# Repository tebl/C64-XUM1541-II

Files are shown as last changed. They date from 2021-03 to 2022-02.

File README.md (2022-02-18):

# C64 XUM1541-II
About a year ago I had a look at my collection of Commodore 64 floppies and decided that it was time, enough time had passed that even I needed to look into backing them up - hoping simply doesn't cut it in the end. I had a look at the available options, then instead of just choosing to buy something like the ZoomFloppy I wanted to build it myself. With the resources available to me [online](https://myoldcomputer.nl/commodore-64/xum1541-promicro/), all of the heavy lifting was already done. The work of transferring the designs to PCB using KiCAD resulted in the previous version, creatively called [C64 XUM1541](https://github.com/tebl/C64-XUM1541). Now that a year has gone by, mostly isolated like most of the world I wanted to make a new revision with few tweaks and so I made the  *C64 XUM1541-II*.

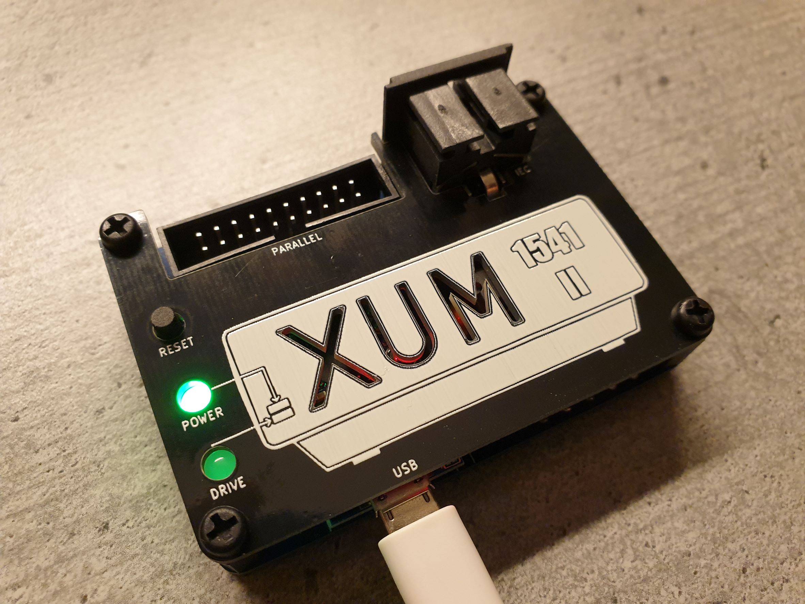
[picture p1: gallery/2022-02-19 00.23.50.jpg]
C64 XUM1541-II with faceplate

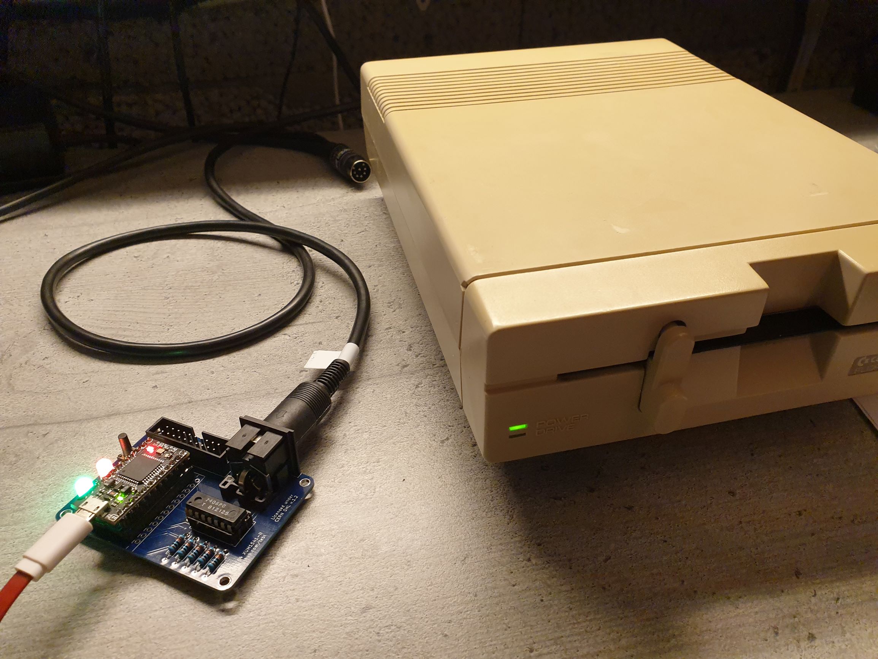
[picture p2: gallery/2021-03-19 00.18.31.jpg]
C64 XUM1541-II


What had somewhat annoyed me that the [C64 XUM1541](https://github.com/tebl/C64-XUM1541) was its apparant limition when it came to running anything past version 0.7 of the [OpenCBM](https://github.com/OpenCBM/OpenCBM/tree/master/xum1541) firmware, so I finally got around to actually reading the documentation that came with it. I don't know the exact point in time the designs parted ways, but thinking practically - I instead just focused on making a version of it that would work. Mostly by adding the components required for the 7406-version of the reference design included with *OpenCBM*.

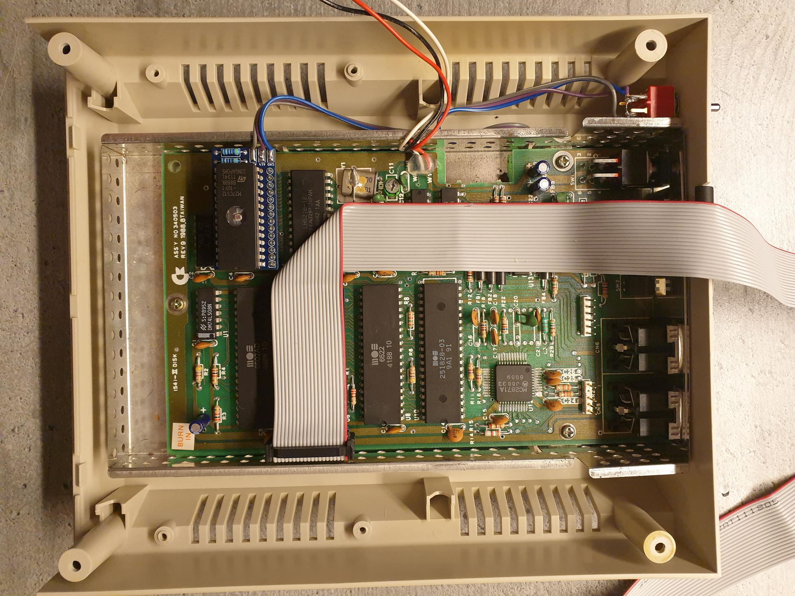
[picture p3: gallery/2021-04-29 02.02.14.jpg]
Internal upgrades


Not quite substantial enough to warrant documenting them as separate projects, I've also taken a look at implementing some of the simpler upgrades for the Commodore 1541-II as they are the type of drives I have available. Read through the included documentation before attempting to perform any of the upgrades as well as ensuring that they actually fit into the drive you have.

# 1> Modules
The following modules are available as part of this project. The additional modules are strictly not necessary as you can simply use the *C64 XUM1541-II* by itself with a drive, the parallel interface will cut the time needed to backup a single disk in half. The remaining modules mainly just affect your experience when using the drive with your physical Commodore 64, but note that most of them have been designed for use with a Commodore 1541-II disk drive.  The SpeedDOS user port adapter has been included for completeness, but before getting excited about the possiblities you should be aware that the speed gains will probably be less than what you'd obtain by simply installing [JiffyDOS](http://store.go4retro.com/categories/Commodore/Firmware/JiffyDOS/) in your [disk drive](http://store.go4retro.com/jiffydos-1541-dos-rom-overlay-image/) as well as  the [computer](http://store.go4retro.com/jiffydos-64-kernal-rom-overlay-image/) itself.

The following table lists all of the modules, click the name to get a more detailed description as well as other information for that specific module. The second and third column has been added to show which module can be used with each other, the 'XUM1541' giving a recommendation when performing backups on a modern computer. The  third column provides a recommendation when you want to use the modified drive with your physical Commodore 64.

| Module | C64 XUM1541-II | Physical C64 | Order  | Description |
| --- | --- | --- | --- | --- |
| [C64 XUM1541-II](https://github.com/tebl/C64-XUM1541-II/tree/main/C64%20XUM1541-II) | required | N/A | [PCBWay](https://www.pcbway.com/project/shareproject/C64_XUM1541_II.html) | C64 XUM1541-II module for backing disks up to modern computer.
| [C64 XUM1541-II Faceplate](https://github.com/tebl/C64-XUM1541-II/tree/main/faceplates) | optional | N/A | [PCBWay FA1](https://www.pcbway.com/project/shareproject/C64_XUM1541_II__Faceplate_FA1_.html) | Optional faceplates suitable for installing on top of [C64 XUM1541-II](https://github.com/tebl/C64-XUM1541-II/tree/main/C64%20XUM1541-II), hiding away most of the electronics in a way that would mimic a case with a minimal amount of work.
| C64 1541-II VIA Adapter | recommended | optional | PCBWay | Adds a parallel interface to your Commodore 1541-II disk drive, can be used with both [C64 XUM1541-II](https://github.com/tebl/C64-XUM1541-II/tree/main/C64%20XUM1541-II) as well as physical computer with a suitable ROM upgrade.
| [C64 1541-II ROM Adapter](https://github.com/tebl/C64-XUM1541-II/tree/main/C64%201541-II%20ROM%20Adapter) | optional | recommended  | PCBWay | Adds a switch to select between ROM images suitable for Commodore 1541-II disk drive with only a single 16KB ROM chip.
| C64 SpeedDOS Adapter | N/A | optional | PCBWay | User port adapter for connecting a 1541-II disk drive with a parallel cable up to your Commodore 64, requires matching firmware on the drive as well as the computer.
| [C64 Kernal Switcher](https://github.com/tebl/C64-Kernal-Switcher) | N/A | recommended  | [PCBWay](https://www.pcbway.com/project/shareproject/Commodore_64_Quad_Kernal_Switcher.html?inviteid=88707) | Using a custom kernal with optimizations for either serial or parallel interfaces is recommended. This board was designed for use with C64 "Longboards".

# 2> Documentation
Building an XUM1541 from scratch and getting the software ready to transfer your own physical disks, is a rather involving process. It is an afternoons worth of a project, but by following the documentation it shouldn't be a difficult task for anyone equipped with a brain for slight engineering. As the project really is just a collection of various modules that you may or may not need, I've separated the information so that the relevant documentation is included as a separate README for each of the [modules](#1-modules) - click the module name for BOM, build instructions and so forth.

When you're ready to start installing software, by first installing the firmware onto the *Arduino Pro Micro* and then installing OpenCBM, there's a separate document covering these details:
- [Firmware installation](https://github.com/tebl/C64-XUM1541-II/blob/main/documentation/firmware.md)

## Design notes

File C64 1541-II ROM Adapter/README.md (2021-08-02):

# C64 1541-II ROM Adapter
The ROM found within the Commodore 1541-II disk drives requires 16KB chips which are somewhat of a pain to source in an age where most kids carry a supercomputer in their pocket, but for some reason the 32KB 27C256 and the 64KB 27C512 are practically leaking out of post box. You could just hardwire the extra pins to use only part of the capacity, or you could add a bunch of switches and a bunch of wires to have a selection firmwares ready at the flick of a switch without needing this adapter. I just love adding little boards everywhere because I'd know that something was hacked in there, so that's the reason this board exists. Note that earlier 1541 drives used two ROM chips, so for those you'd need a different solution that is presented here.

Worthy of noticing early on, is that the 1541-II doesn't really have very much available space to work with, so there will be some compromises that needs to be made in order to fit everything in the space available. For that reason I recommend following the supplied build instructions, only deviating once you've understood the reason for building it in this way.

- [1> Building it](#1-building-it)
  - [1.1> Soldering it together](#11-soldering-it-together)
  - [1.2> Preparing the EPROM](#12-preparing-the-eprom)
  - [1.3> Testing it out](#13-testing-it-out)
- [2> Schematic](#2-schematic)
- [3> BOM](#3-bom)

# 1> Building it
Building the unit assumes you have at least minor experience soldering things together, recommended is at least a soldering station with adjustable temperature to get started. Commonly you'll want to start out with some 60/40 solder tin, but this'll naturally depend on availability in your area.

With the requirements when it comes to equipment sorted, now it's time to do even more shopping - head on over to the [BOM](#3-bom)-section for a specific list over components needed. Note that with sites such as ebay, AliExpress and similar sites that sell cheap chinese components, you'll need to treat these more as a suggested search term and look for something that for the most part matches the gallery pictures. I tend to use only the cheapest components available, so it should be somewhere in the top of your results.

Remember that part where I told you there'd be compromises? The first one is that the assembled adapter would be too tall to fit under the drive mechanism, meaning that we'd only be able to fit a single DIP socket. Your options are to either to remove the one already found on the 1541-II mainboard, or you need to solder the EPROM chip directly to the adapter board. I personally prefer the latter, I can always build another adapter board if it comes down to it - so this is also the solution that will be described when going forward.

## 1.1> Soldering it together
I suggest that you start out by studying the PCB so that you have a general overview over the components that are needed, In particular, pay attention to the markings on the board for the components that need to be installed in a specific orientation such as the EPROM. The pins marked with the circles around them will be used for the pins that will pass through the board and into the 1541-II mainboard socket below, note that one of these rows will be underneath the EPROM.

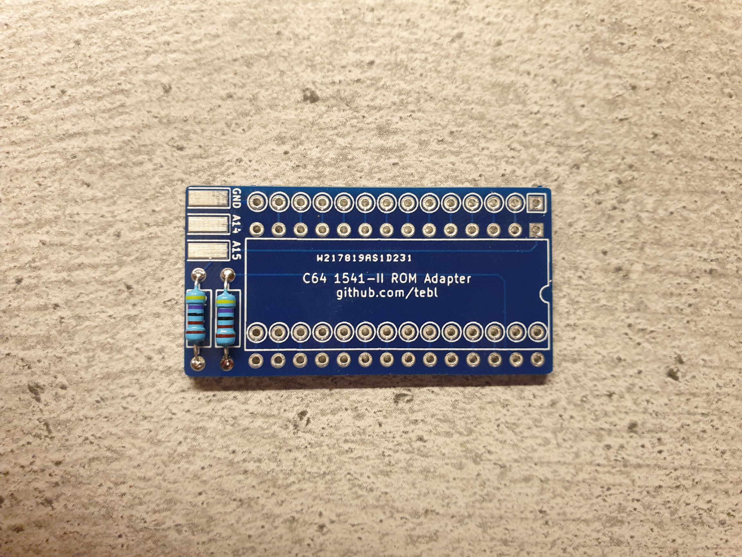
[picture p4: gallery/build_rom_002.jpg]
Build C64 XUM1541-II 002


Here we've gone ahead and installed the two resistors needed, there isn't much else to say about the matter. If the silkscreen fits, then you must commit and all that - just to say more than what was strictly needed (there is no polarity).

Here we've gone one step further by getting started on the pins that will go into the socket found on the 1541-II mainboard, because of the height limitations we won't be able to simply use pin headers as expected. We'll instead need to use the *"neat"* method instead, simply put by using the long pin versions of female pin headers. Using a temporary socket as a template, lightly solder the top of the pins to the adapter board using as little solder as possible. When done, observe the result from the underside to ensure that the solder has flowed into and filled the hole completely to ensure that it won't simply fall apart later. Cut off the top of the pins as close as you can to the adapter board, in particular those that will be overlapped by the EPROM. For reference, the holes that we're soldering components to at this point is marked with rings around the holes.

When happy with the results, we're ready to solder in an already prepared EPROM (27c256/27c512) or EEPROM (w27c512). Check out section [1.2> Preparing the EPROM](#12-preparing-the-eprom) if you need a bit of guidance when putting data onto the chip before soldering it to the board. You can have a total of four different ROM images when using the 27c512 or w27c512 chips, but I tend to only install a single DPDT (ON-OFF-ON) switch - giving me three different usable images instead of four without needing to add a second switch. Solder the chip into place once you've got the correct data on it, trim the pins to ensure that they don't accidentally make contact with something it's not supposed to.

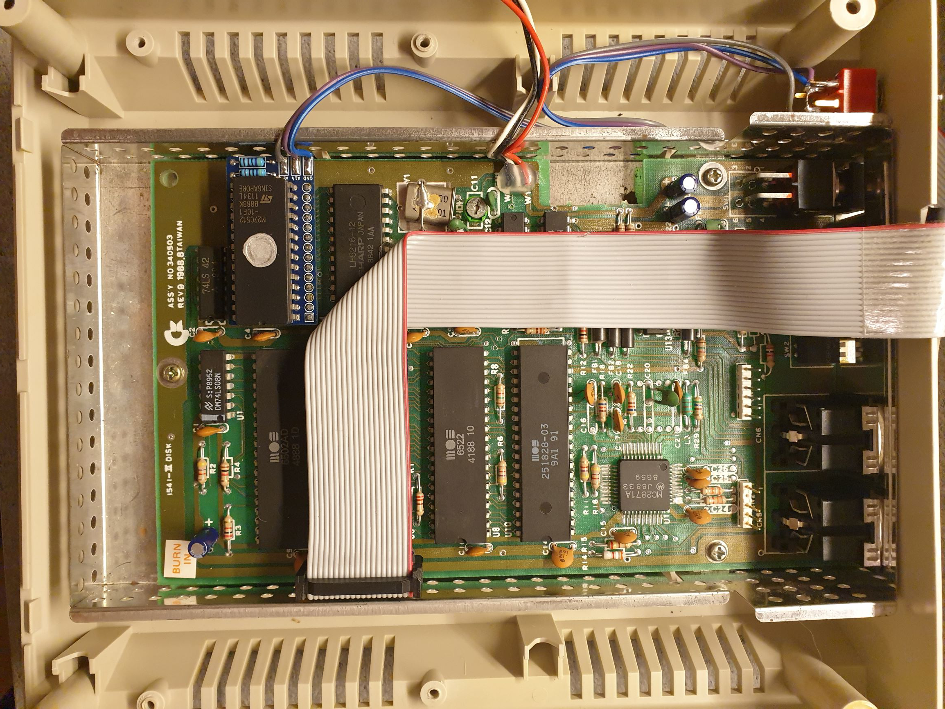
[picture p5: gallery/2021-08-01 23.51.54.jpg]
Switch installation


The DPDT has 6 pins, the easiest way of wiring it up is to connect the two center pins to the point marked GND. The two address lines is connected on either of the sides, but not on the same row. Doing it this way means that the first 16K image will never be accessed, putting the switch in the center position will be the last 16K image (ideally the original firmware). Even with the RF-shield in place, there's plenty of room on the sides - just remember to measure once and drill as many times as it takes.

## 1.2> Preparing the EPROM
The Commodore 1541-II drive has a single ROM socket on the mainboard and as already mentioned it is 16K in size, so with a 27c512 in place on the adapter we'll have the capability of selecting between four different 16K slots. When only installing a single DPDT-switch as described in the previous section, we'll only have access to the last three slots though we'll just be putting the default ROM there as well (in case we change our mind about it at a later point).

To be honest there isn't all that much that makes sense to install in the slots, the most common is using [JiffyDOS](http://store.go4retro.com/jiffydos-1541-dos-rom-overlay-image/) as well as the original firmware referred to as [1541-II.251968-03](http://www.zimmers.net/anonftp/pub/cbm/firmware/drives/new/1541/). Given that I wanted to play around with [SpeedDOS](http://www.zimmers.net/anonftp/pub/cbm/firmware/drives/new/1541/hacks/), I'm using that as the third alternative. Merging the four files together into a 64K file ready for flashing onto the aforementioned 27c512 chip can be done like the following:

```
copy /b 1541-II.251968-03.bin + JiffyDOS_1541-II.bin + 1541-II-relocated.bin + 1541-II.251968-03.bin 1541-II-firware.bin
```

Flash the file onto your actual chip using an EPROM burner such as the MiniPro TL866, there should be plenty of information on doing this out there on the wet and wild Internet.

## 1.3> Testing it out
Initial testing of the replaced ROM using the adapter is easily done by simply turning on the drive and observe that is turns on, spins the drive and then finally stops again (this is a good sign that the drive is working as expected). The various ROM replacements will normally write a different string to the error channel, when used with a device such as the XUM1541 or XUM1541-II this is the drive identification when using OpenCBM (*cbmctrl.exe detect*).

With the drive turned off, flick the switch or switches that you may or may not have installed. Probably wouldn't hurt anything if you forget to switch it off, but there's not much of a chance that it'll do much else than crash once the ROM suddenly gets replaced. Note down the values you get and the position of the switches, mark accordingly so that you don't need to guess at a later point.

# 2> Schematic
The supplied KiCad files should be sufficient as both a schematic and as a  starting point for ordering PCBs (basically you could just zip the contents of the export folder and upload that on a fabrication site), the schematic is also available in [PDF-format](https://github.com/tebl/C64-XUM1541-II/tree/main/documentation/schematic) and this is what you'll need to print and work your way through this things don't work as expected after assembly.

# 3> BOM
Most parts should be easy to get a hold of from your favourite local electronic component shop, but given that I don't have access to such shops where I live so everything was based on whatever I could get cheapest from eBay/AliExpress (free shipping, but plan on waiting 3-4 weeks for delivery). 

| Reference | Item | Count | Order  |
| --- | --- | ----- | --- |
| Adapter PCB | Fabricate using Gerber files | 1 | [PCBWay]()
| R1,R2 | 4k7 (4700) ohm resistor | 2
| A1 * | 2.54mm long female pin headers of suitable length | 2
| U1 | 27C256, generic 27C512 EPROM or a W27C512 EEPROM | 1
| SW | DPDT On-Off-On switch and hookup wire

*) Given that we are only using parts of the female pin headers with long pins, we don't really need a specific amount of pins though you'll have an easier time if you kind find ones with at least 14 pins (the remainders would either be cut off or used for a different project). This is described in more detail in the build section.

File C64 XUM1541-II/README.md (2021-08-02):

# C64 XUM1541-II
If you came to this github-repository looking for the implementation of an XUM1541, then you've come to the correct place and this folder contains all of the files needed to build one for yourself. The necessary details first of course, I didn't design the original XUM1541 - the earlier heavy lifting was already done and detailed in an  article [online](https://myoldcomputer.nl/commodore-64/xum1541-promicro/). My contribution was reading it, then adapting it for easier use by designing a PCB as part of a personal project available at [C64 XUM1541](https://github.com/tebl/C64-XUM1541).

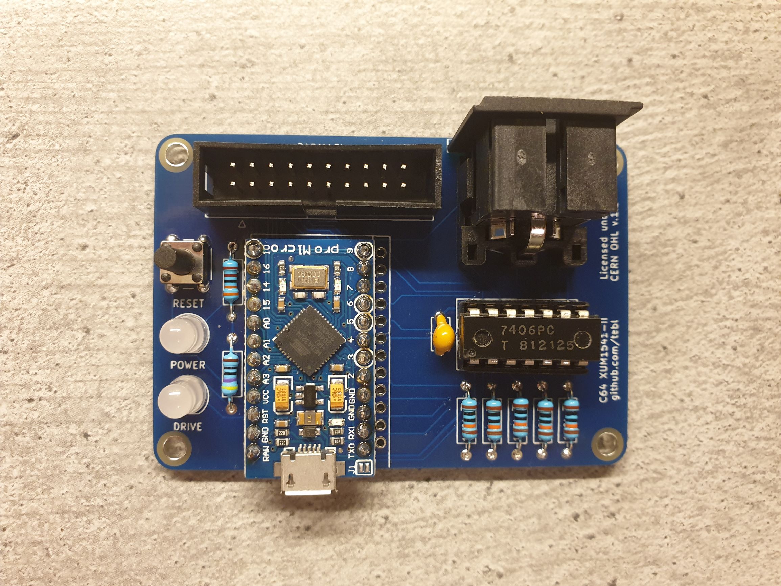
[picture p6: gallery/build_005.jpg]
C64 XUM1541-II


This however is an updated version from that design, mainly by integrating the 7406 inverter as described in the [OpenCBM](https://github.com/zyonee/opencbm/tree/master/xum1541) documentation. In theory this should allow the device some more durability when used together with multiple devices connected to the IEC-bus, but while I haven't had any issue with the original device - the main objective was to modify it for use with the later versions of the OpenCBM firmware (0.8). A secondary objective was to make it a more visually pleasing device from the original, which is pretty hard when dealing with a bare PCB - so I designed a separate faceplate to be installed on the top though this is a completely optional addition.

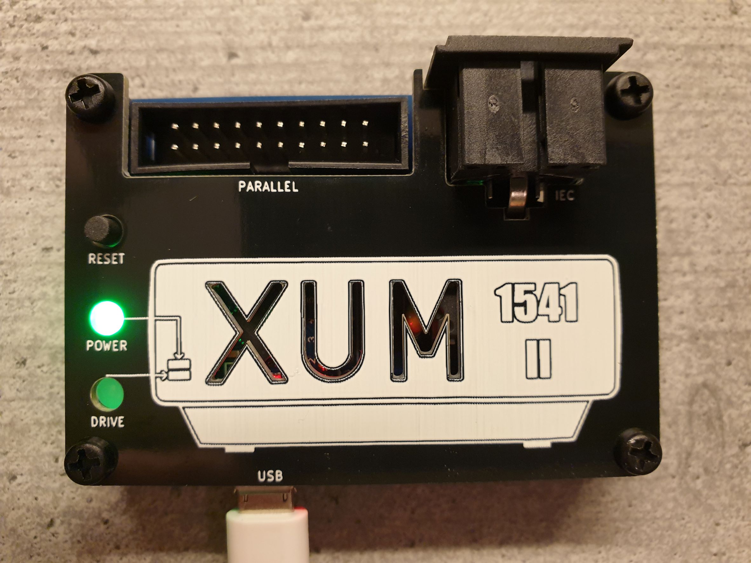
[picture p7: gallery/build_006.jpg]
C64 XUM1541-II with faceplate


- [1> Building the C64 XUM1541-II](#1-building-the-c64-xum1541-ii)
  - [1.1> Soldering it together](#11-soldering-it-together)
  - [1.2> Assembling the unit](#12-assembling-the-unit)
  - [1.3> Testing it out](#13-testing-it-out)
- [2> Schematic](#2-schematic)
- [3> BOM](#3-bom)

# 1> Building the C64 XUM1541-II
Building the unit assumes you have at least minor experience soldering things together, recommended is at least a soldering station with adjustable temperature to get started. Commonly you'll want to start out with some 60/40 solder tin, but this'll naturally depend on availability in your area.

With the requirements when it comes to equipment sorted, now it's time to do even more shopping - head on over to the [BOM](#3-bom)-section for a somewhat specific list over components needed. Note that with sites such as ebay, AliExpress and similar sites that sell cheap chinese components, you'll need to treat these more as a suggested search term and look for something that for the most part matches the gallery pictures. I tend to use only the cheapest components available, so it should be somewhere in the top of your results.

## 1.1> Soldering it together
The construction of this unit should be straight-forward, specifically as there are only a handful of components to deal with. None of the components overlap in any way, so while there are certainly an easier route - that one would normally go from first installing the smallest components and working your way up from there. 

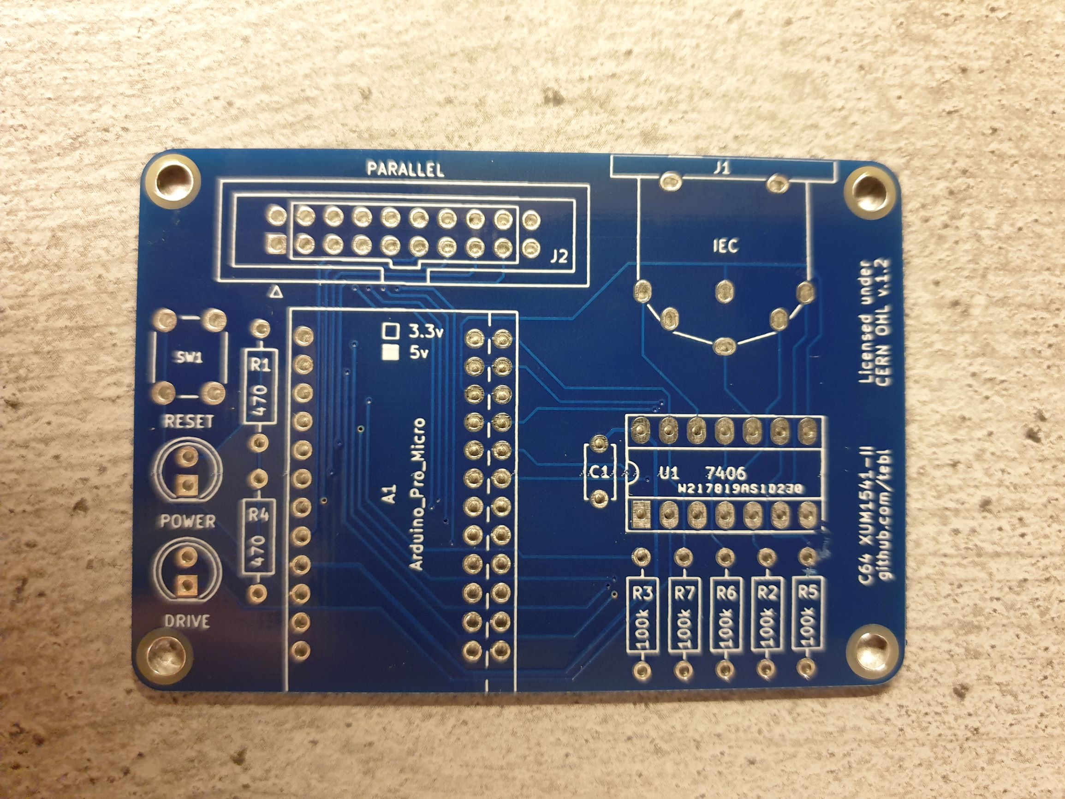
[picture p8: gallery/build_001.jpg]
Build C64 XUM1541-II 001


I suggest that you start out by studying the PCB so that you have a general overview over the components that are needed, possibly also making a mental note over the components specificly listed in the BOM as optional (component count in parenthesis). In particular, pay attention to the markings on the board for the components that need to be installed in a specific orientation (LEDs and the single IC socket).

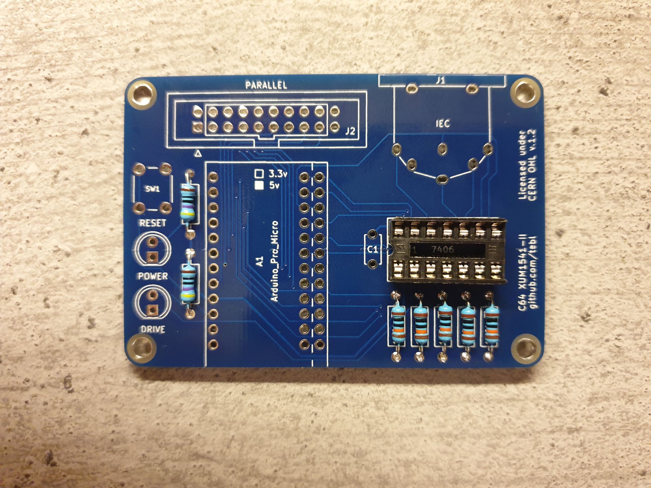
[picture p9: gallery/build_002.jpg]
Build C64 XUM1541-II 002


Here we've gone ahead and installed all of the resistors, if you've bought the components as part of a kit you should note that there are two different values that you can easily pick out based on their colour bands and the number included. The IC socket have an indent on one side, this should be matched to the silkscreen on the board.

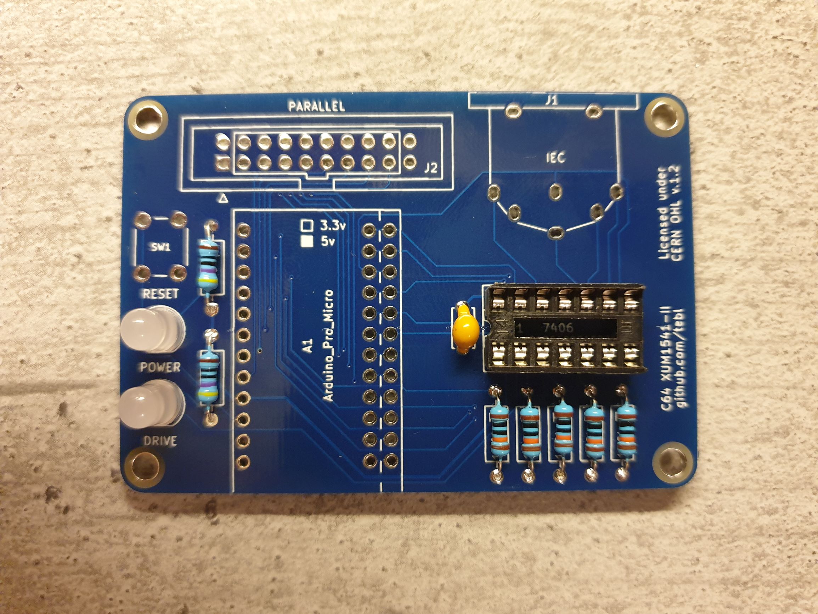
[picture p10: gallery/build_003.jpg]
Build C64 XUM1541-II


The single capacitor doesn't have a polarity so just stick it in place. The LEDs won't function when installed in the wrong orientation, ideally this should be as easy as matching the flat side to the one on the board. However there are quite a few cheaper LEDs where this isn't as easy to determine, so instead I'll just recommend that you put the shortest pin into the hole on the *flat* side. Given that you'll no doubt want a faceplate, you need to get this on the board straight - what I recommend is that you solder one of the pins, then reheat and push the component flush with the board before soldering the remaining pin.

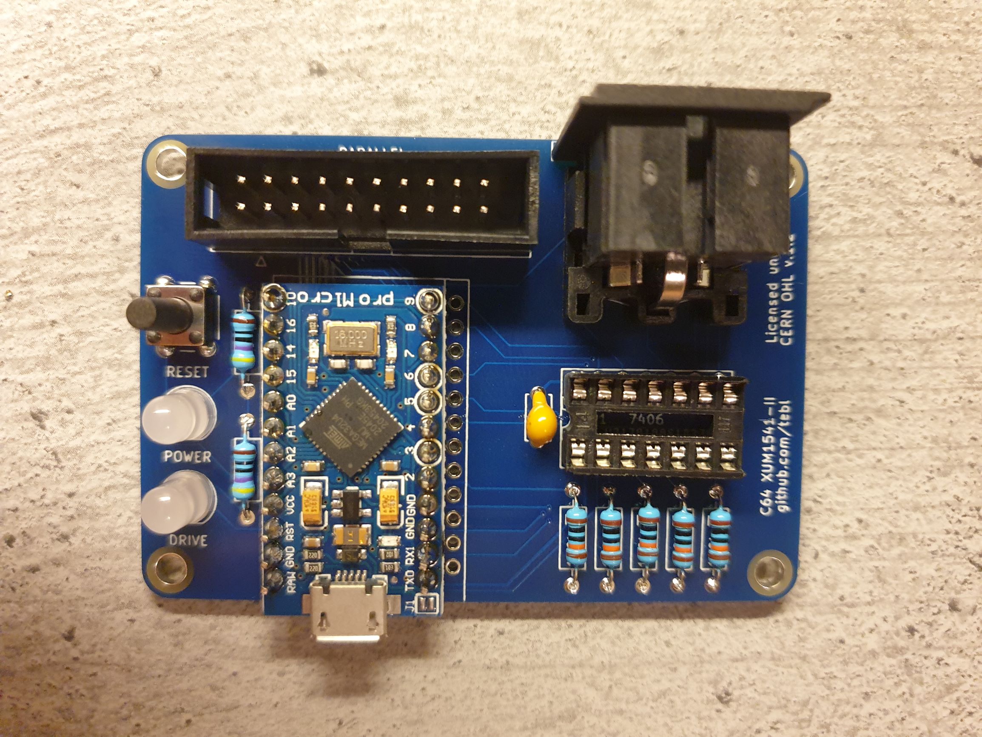
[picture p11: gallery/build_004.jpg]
Build C64 XUM1541-II

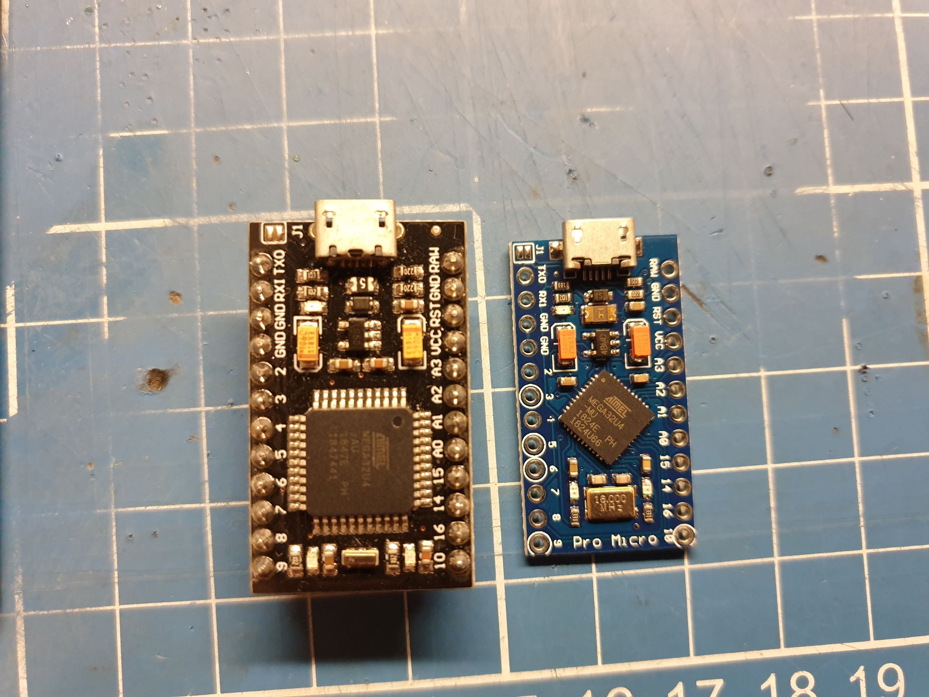
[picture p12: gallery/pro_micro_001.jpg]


Here we've jumped a bit ahead and finally you've found the answer to one of your original questions; why does the outline for the Arduino Pro Micro have three sets of pins on it? As you can see from the other picture added, there are a few different layouts for the Arduino Pro Micro boards - one is wider than the other! Pick the one that matches your boards before soldering pin headers onto either of the modules.

The last component that we really need to discuss is the momentary switch, mainly that it needs to be tall enough to poke through the faceplate on top. I've not found out how ebay listings measure the height of their switches, mainly because I just picked up a kit with different size switches and picked what fit. What I can tell you is that measuring just the black protruding plastic part, it needs to be around 8mm - measured from the PCB it sits around 11.5mnm above it.

Time to shut off the soldering iron. Feel the strongth welling, return to the next chapter for the exciting conclusion to this documentation. Spoiler warning: there will be a section after that one.

## 1.2> Assembling the unit
At this point we've added just about everything but the 7406, mainly just because I like dragging things out. Before doing so, I recommend spending some time to get the firmware installed onto the Arduino Pro Micro. It shouldn't matter, but it given the number of fake 7406 chips floating around it's better doing it this way. Given that installing the firmware and the accompanying OpenCBM software can be a bit more difficult than it should be, I've put together a separate [document](https://github.com/tebl/C64-XUM1541-II/blob/main/documentation/firmware.md) that should go into just about every bit of details needed to get all that set up. Return here when you're ready to move onto testing things out.

Build C64 XUM1541-II

Here we've inserted the aforementioned 7406, and the device should now be ready for actual testing. Skip to the next chapter if you don't want a faceplate, because - why wouldn't you want a faceplate? They're cool.

Build C64 XUM1541-II

The faceplate is just a simple PCB, the suggested way of attaching it is by using components found in cheap *M3 nylon hex* kits. It will look at its best when using an 8mm nylon hex standoff (F-F), then adding screws from both sides. If, on the other hand, you want to stay within the kit - then I suggest using the 8mm M-F standoffs, add M3 nuts on the bottom and snip off the remaining part of the nylon screw that'll poke through. Add screws on top.

## 1.3> Testing it out
When ready to test things out, we need to do some safety notifications - mainly, you can't buy any new and unused Commodore 1541 disk drives so treat them with care. They aren't plug and play like we're used to today, if you start plugging and unplugging cables while things are powered on you should probably say a prayer. Neither probably won't actually cause your vintage computer hardware to explode, but it'll happily kill your hardware in less spectacular ways. Got that? Good.

Ensure that the 1541 disk drive as well as the C64 XUM1541-II is not powered on, now connect the  IEC cable between them. Power on the disk drive, then plug the device into your modern computer. Go through the final section of my [firmware]([document](https://github.com/tebl/C64-XUM1541-II/blob/main/documentation/firmware.md)) document for some initial hints on copying your first disk, check out the software directory for a few of the batch files I personally use with the device if you just want some basic functionality without looking into all of the options (see OpenCBM documentation for that).

# 2> Schematic
The supplied KiCad files should be sufficient as both a schematic and as a  starting point for ordering PCBs (basically you could just zip the contents of the export folder and upload that on a fabrication site), the schematic is also available in [PDF-format](https://github.com/tebl/C64-XUM1541-II/tree/main/documentation/schematic) and this is what you'll need to print and work your way through this things don't work as expected after assembly.

# 3> BOM
Most parts should be easy to get a hold of from your favourite local electronic component shop, but given that I don't have access to such shops where I live so everything was based on whatever I could get cheapest from eBay/AliExpress (free shipping, but plan on waiting 3-4 weeks for delivery). 

| Reference | Item | Count | Order  |
| --- | --- | ----- | --- |
| Cartridge PCB | Fabricate using Gerber files | 1 | [PCBWay](https://www.pcbway.com/project/shareproject/C64_XUM1541_II.html)
| Faceplate PCB | Fabricate using Gerber files | (1)| [PCBWay FA1](https://www.pcbway.com/project/shareproject/C64_XUM1541_II__Faceplate_FA1_.html)
| A1 * | Arduino Pro Micro | 1 |
| C1 | 100nF ceramic capacitor (5mm pin spacing) | 1 |
| D1,D2 | 5mm LED | (2)|
| J1 | Female S-terminal 6pin DIN PCB | 1 |
| J2 | 2x10 male IDC socket | (1) |
| R1,R4 ** | 470 ohm resistor | (2)| 
| R2,R3,R5,R6,R7 | 100k ohm resistor | 5 | 
| SW1 | 6x6x11mm right-angle momentary button | 1 |
| U1					| 7406 (DIP-14) | 1 |
| Mounting *** | Nylon M3 hex standoffs 8mm | (4)|
| Mounting *** | Nylon M3x6mm nylon screws | (4)|
| Mounting *** | M3 nylon nut | (4)|  

*) I've purchased a couple of different Arduino Pro Micro boards that had a different physical size, so take care to match up the pins to the PCB so that you solder it up to match the board you own. 

**) The value to be installed here needs to match the LEDs installed, value should be acceptable for most cheaper LEDs. If the using LEDs in any way listed as bright or are in any way clear, you'll need to calculate a suitable value in order to not blind yourself when looking at them.

***) The easiest way of ordering these is to just one of the M3 nylon standoff kits on ebay, AliExpress or any similar sites. That way you'll get more than what you need in various sizes for future projects as well.

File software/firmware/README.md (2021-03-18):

The firmware found in this directory was distributed as part of the repository at https://github.com/zyonee/opencbm/tree/master/xum1541. It is included here as a last known working firmware revision, later versions may have updates that have not been tested with this device.

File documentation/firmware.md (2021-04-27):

# 1> Firmware installation
The firmware that goes onto the Arduino Pro Micro is often referred to as an  Arduino Sketch, something that isn't actually fitting in this case as the design uses the hardware without the software parts of the Arduino project - we'll be flashing the Atmel Atmega32 MCU directly using more generic tools instead. The next step is installing a suitable USB-driver followed by the OpenCBM software package.

This document will for the most part focus on MS Windows as that is what I have, for all other systems you'll need to fill in quite a few of the gaps yourself. While you may not need to perform all of these steps exactly as described within this document, there are enough of little pitfalls that you can quicly fall into. For that reason I recommend that you read through the entire document before attempting to install any of the components, then do **exactly** as described. 

- [1.1> Flashing AVR](#11-flashing-avr)
- [1.2> Install USB-driver](#12-install-usb-driver)
- [1.3> Install OpenCBM](#13-install-opencbm)
- [1.4> Try copying a disk](#14-try-copying-a-disk)

## 1.1> Flashing AVR
While we could download the source code for the firmware and compile it ourself from the authors [github](https://github.com/zyonee/opencbm)-repository, we're instead going to use a precompiled version of the firmware instead - it'll be distributed as an Intel HEX-file. This is the same file type as used by EPROM burners such as the MiniPro TL866 referred to elsewhere in this project, but that would require knowing intuitively how to set the fuses for the MCU - I have no idea about such things, so I recommend using a program specificly made for dealing with MCUs.

One such program, it is also the one I'll be referring to for the remainder of this document, is usually referred to as just - *avrdude*. A distribution of this software that has been prepared for installation on a modern copy of MS Windows is [WinAVR](https://sourceforge.net/projects/winavr/). With other operating systems you'll probably find a similar package as it's practically available everywhere, ignore the obvious Windows-stuff when going forward.

At this point, you should already have installed a version of *avrdude*. The next step is just simply downloading the HEX-file as mentioned earlier, you can grab current version I've verified working from my [repository](https://github.com/tebl/C64-XUM1541-II/tree/main/software/firmware) or a bleeding edge copy from the original authors [repository](https://github.com/zyonee/opencbm/tree/master/xum1541). Given that the *C64 XUM1541-II* hardware integrates a 7406 inverter, it should be named  "xum1541-PROMICRO_7406-v08.hex" (depending on version).

**NB!** When downloading the file, make sure that you save this file from the raw-format - simply right-clicking a file from within the github-page will save it along with a bunch of html inside it. Click the file, then the *RAW* button - then finally save the file with the proper content. Alternatively you can view the repository in the web-browser, click the green *Code* button and then select *Download ZIP* to get a copy of everything.

Before we can flash the Arduino Pro Micro, we'll need to know which COM-port Windows have assigned to your it. Connect it to your computer using a suitable USB-cable, try a different one if nothing at all happens on your computer at this point - usually it'll make a *ding* sound or something to that effect. Check out *device manager* and take a look at the Ports-section, you should have one here - this is **NOT** the one you want! The one you actually want to use will only be shown for 8 seconds, so keep this window open and reset the Arduino Pro Micro by pressing the reset button **twice**.

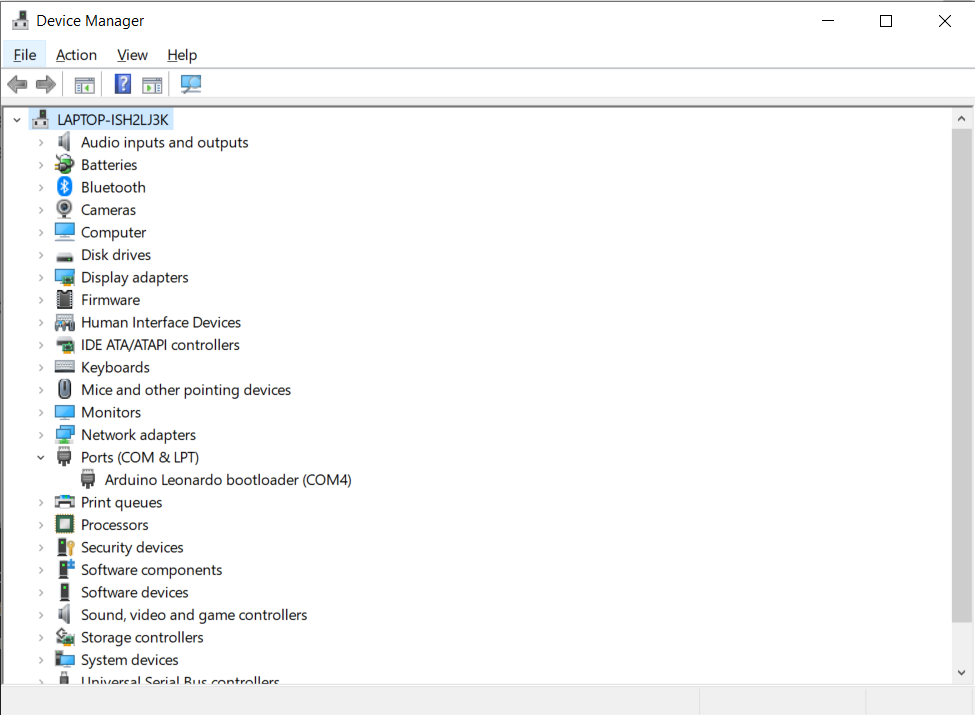
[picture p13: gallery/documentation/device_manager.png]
device_manager


On my computer the port showed up as com4, you need to pay attention and make a note of what this number is on your computer. After the already mentioned 8-second timeout it'll change again, but never mind that - as it is this first one we need to use with *avrdude*. Type in the command as below, substituting your actual com-port, but do **NOT** press ENTER at this point. Reset the Arduino Pro Micro again by pushing *reset* **twice** and then quickly press ENTER to run the command (you'll have 8 seconds). 

```
avrdude -p m32u4 -c avr109 -P com4 -U flash:w:xum1541-PROMICRO_7406-v08.hex
```

If all things go as expected you should get something like the following, just ignore the specifics and ensure that it at the moment verifies that the firmware was written correctly. If it times out or bombs out with an error message, you were probably too late when resetting the Arduino Pro Micro so just try it again until you finally succeed.

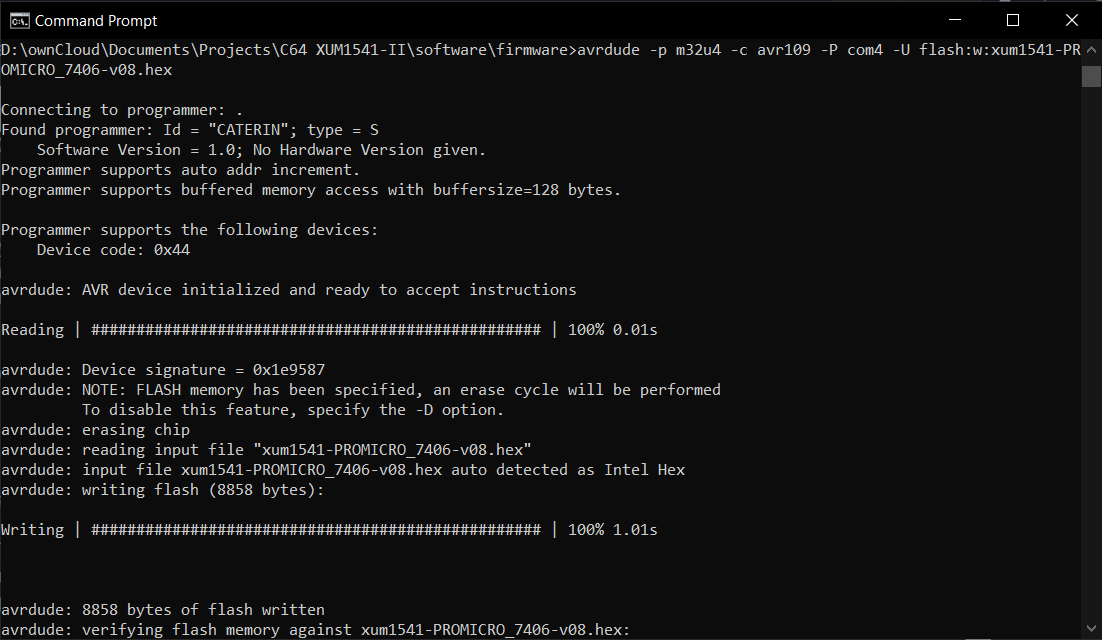
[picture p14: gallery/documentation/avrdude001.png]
avrdude001

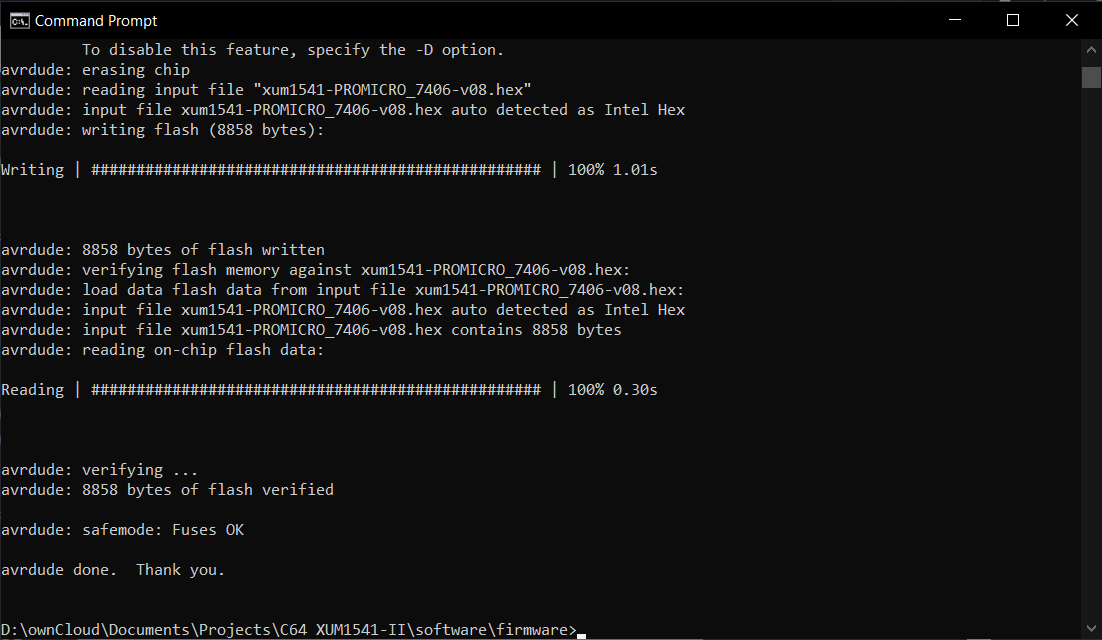
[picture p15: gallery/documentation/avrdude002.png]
avrdude002


At this point the Arduino Pro Micro has seized being an Arduino Pro Micro, it is now a XUM1541. Disconnect the USB-cable and then reconnect it, you should now get a new notification from Windows about an xum1541 having been plugged in instead. Without installing USB-drivers it won't work, so let's do that next.

## 1.2> Install USB-driver
The next step is installing a USB-driver suitable for use with the XUM1541, the easiest way of doing this is by using a driver installer called [Zadig](https://zadig.akeo.ie/). List all devices from the *options* dropdown-menu, then locate the XUM1541 device in the device listing. In the target section of the driver selection, click up/down until it says **libusb-win32**. Now you can finally click install/reinstall driver in a form that should hopefully work (refer to picture below if needed).

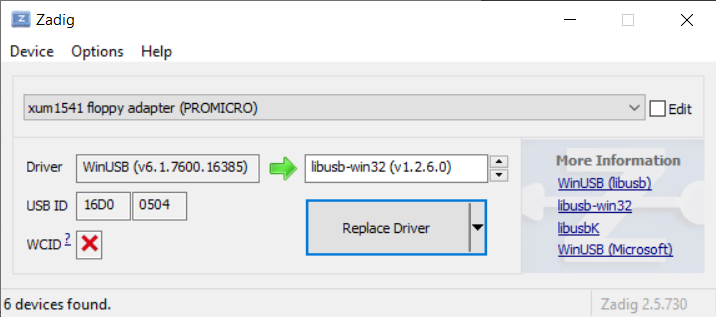
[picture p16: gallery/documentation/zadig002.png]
Zadig


**NB!** Later in this document, we'll get to the installation of OpenCBM. As part of the installation, it'll ask you for permission to install a USB-driver for you - this won't work and it'll just override the driver we just installed. If you did this, then from Zadig - you'll need to enable *List all Devices* from *Options* and then select the xum1541 device from the dropdown list and then click *replace driver*. Do **NOT** randomly mess around with any of the other devices listed, the results probably won't be easy to fix.

Remember earlier when we checked out *Device Manager*? Before continuing I recommend ensuring that the XUM1541 is now listed as expected, it should now show up in a different section than where we found the Arduino Pro Micro (back when it was an Arduino). For reference, see the picture below.

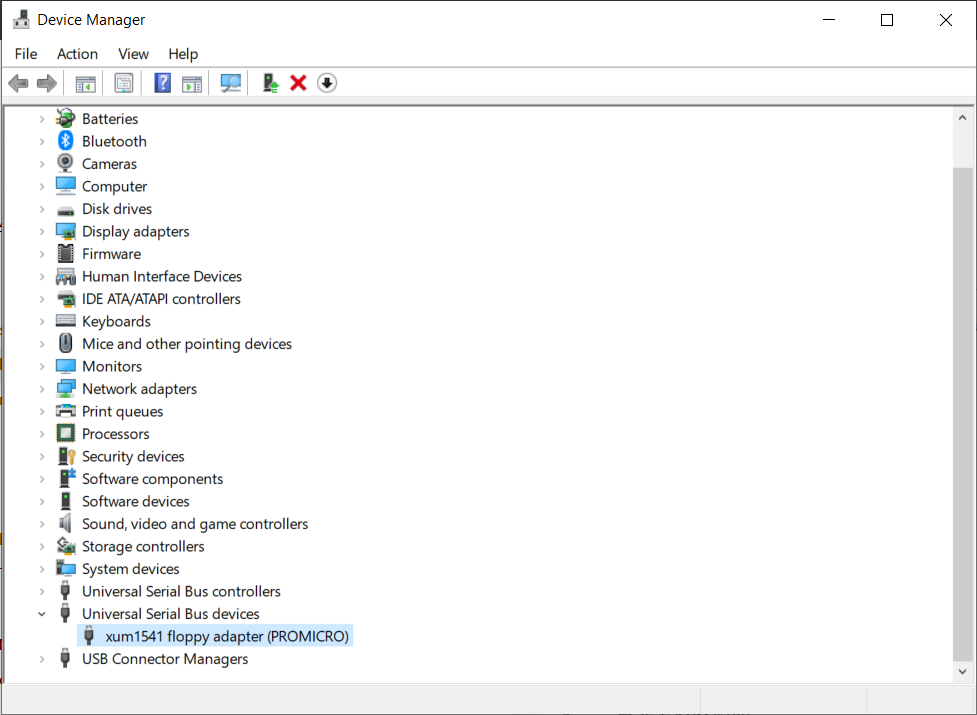
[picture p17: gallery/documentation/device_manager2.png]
Device Manager


## 1.3> Install OpenCBM
The actual OpenCBM tools can be downloaded from the creators homepage at [spiro.trikaliotis.net/opencbm](https://spiro.trikaliotis.net/opencbm#download), it's a zip-file and you'll need to extract it to a folder somewhere. Open a CMD-shell in administrator mode, find the directory where you left the extracted file and finally "install" the package by using the following command:
```
install.bat xum1541
```
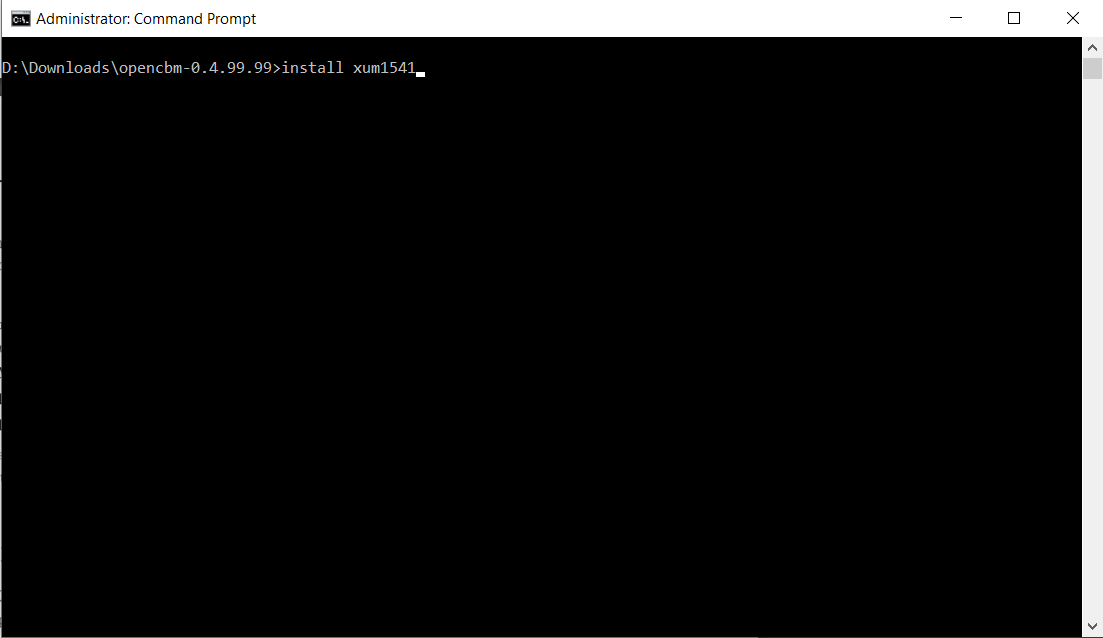
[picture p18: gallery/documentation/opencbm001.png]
opencbm001


**NB!** At a certain point in the installation, it'll ask if you want to install the USB-driver - answer **NO** to this as the driver will probably only work with the ZoomFloppy board. If you accidentally install it, refer to section [1.2> Install USB-driver](#12-install-usb-driver) details on fixing this. It happens, I've done it and now you need to fix it before continuing.

OpenCBM will now be installed on the system, but it's not a graphical application - it is more a suite of command-line tools. You can verify that the program has been installed correctly by opening up a *Command Prompt* (*cmd.exe*), then change your working directory to *C:\Program Files\opencbm* (or something similar, depending on Windows localization). You can now attempt to run some of the commands in order to verify that Windows is able to communicate with the module, for example the following:
```
cbmctrl.exe detect
```
With no 1541 device connected to the XUM1541 you probably won't get any meaningful feedback, or any at all. In this case, no feedback is good news as that means no error messages. For the love of all things *Commodore*, do **NOT** plug or unplug any sort of cable when either one of the components have power applied to it! Unplug the USB-cable to the XUM-1541, ensure the 1541 is still shut off and then finally connect the IEC cable between the two. Connect the XUM1541 to your computer, and only at this point should you actually switch on the 1541. Running the same command you should now see that a 1541 have been detected, the name will be dependent on the kernal installed in the drive itself.

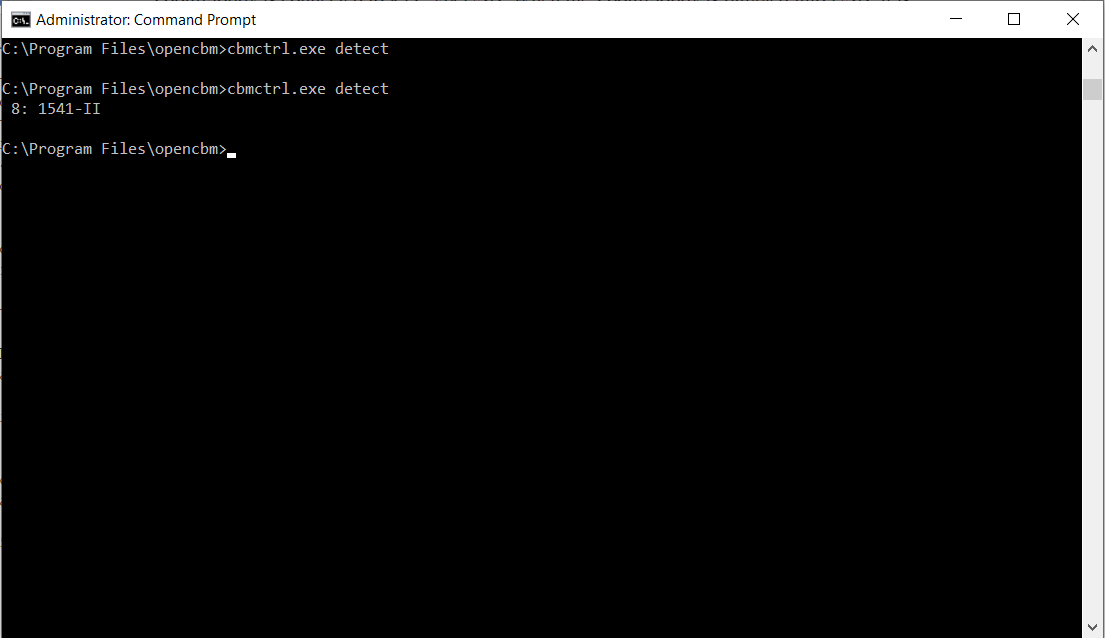
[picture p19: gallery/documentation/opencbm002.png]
opencbm002


## 1.4> Try copying a disk
You probably bought or built this device in order to copy your aging floppy disks, so let's just try copying a disk to ensure that everything actually works. The command you're probably looking for is something like the following:
```
d64copy.exe 8 test.d64
```
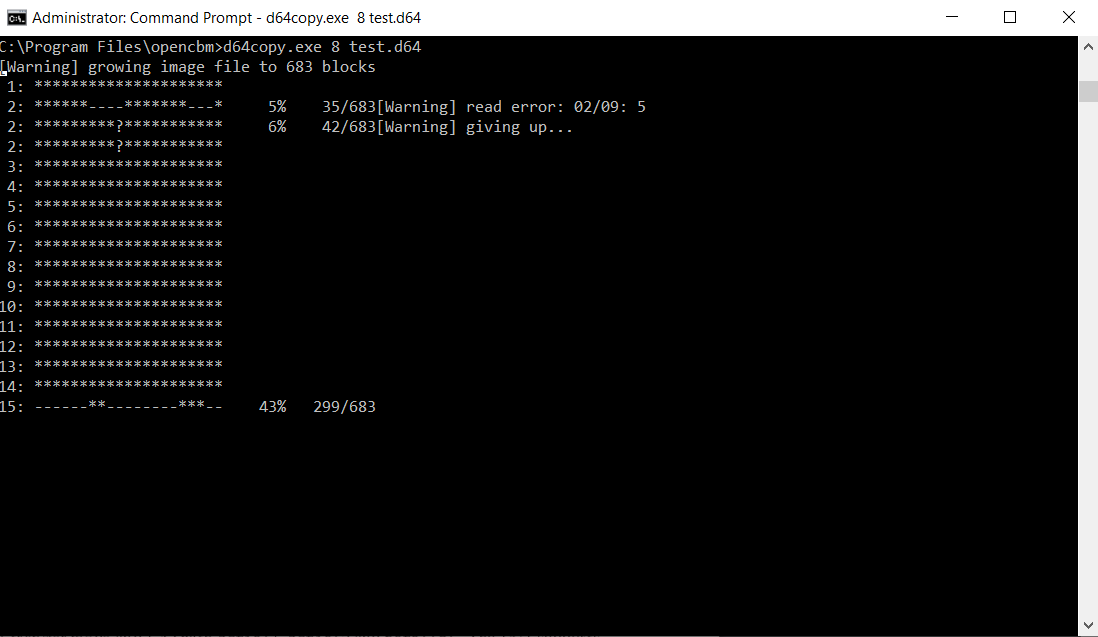
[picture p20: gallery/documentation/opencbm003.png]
opencbm003


If all goes well, this should make a copy of the disk in drive 8 to a file called *test.d64*. There is a more comprehensive manual that comes with opencbm, it goes into a lot more detail when it comes to describing the various functions that can be performed when using a XUM1541-device. 

Check out the software directory of this project for a selection of batch-files, they should help somewhat in automating basic tasks and they are what I'm using at this point. There are a few graphical programs made for it, but I find the command line a lot quicker in practice. The *copy.bat* file takes a number as a  parameter, it will then read side A of the disk inserted and then prompt you to turn over the disk before copying side B (it'll one d64-file for each in a sub-directory named disks). 
```
copy.bat 16
```
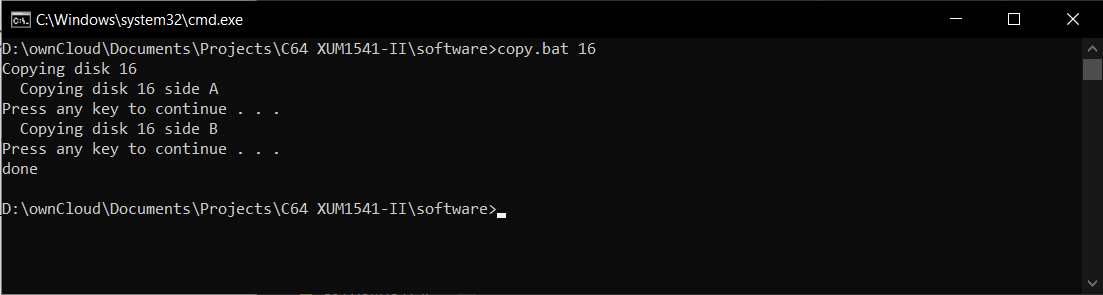
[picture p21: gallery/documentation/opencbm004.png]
opencbm004


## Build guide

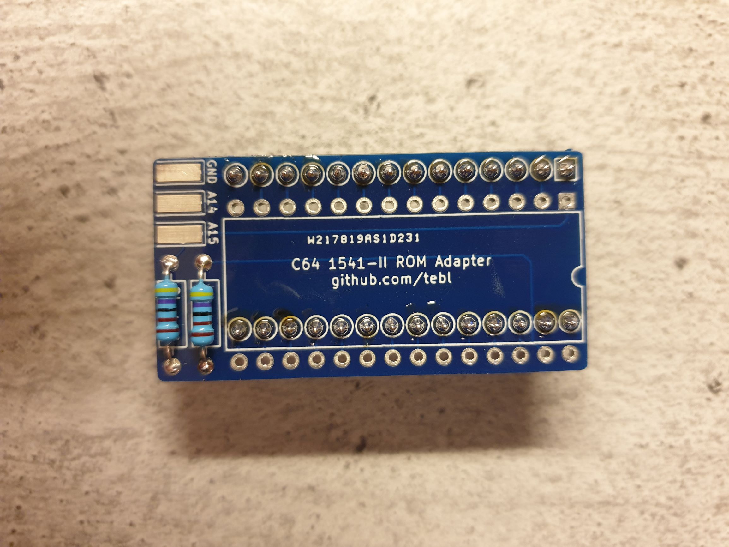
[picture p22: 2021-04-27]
gallery/build_rom_003.jpg

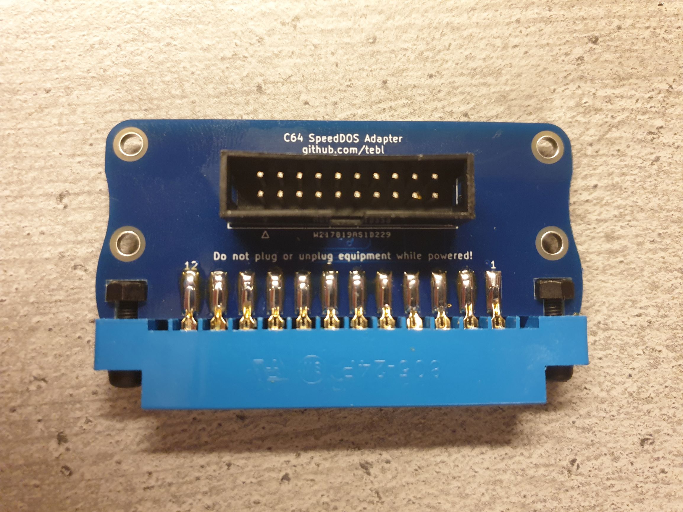
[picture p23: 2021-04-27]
gallery/build_speeddos_003.jpg

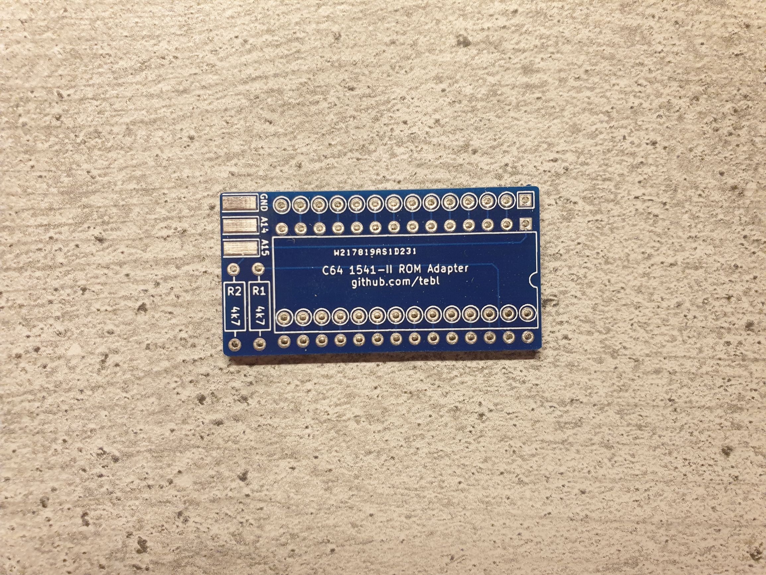
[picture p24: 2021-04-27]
gallery/build_rom_001.jpg

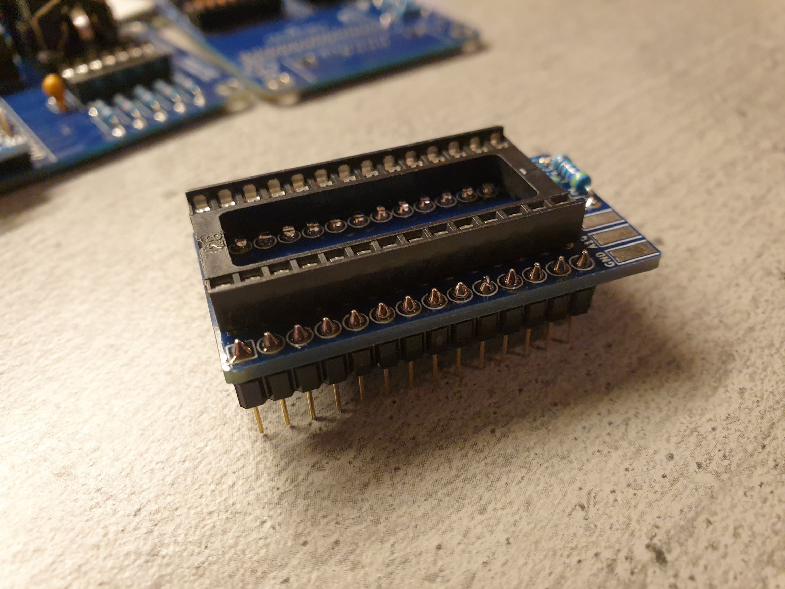
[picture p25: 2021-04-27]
gallery/build_rom_004.jpg

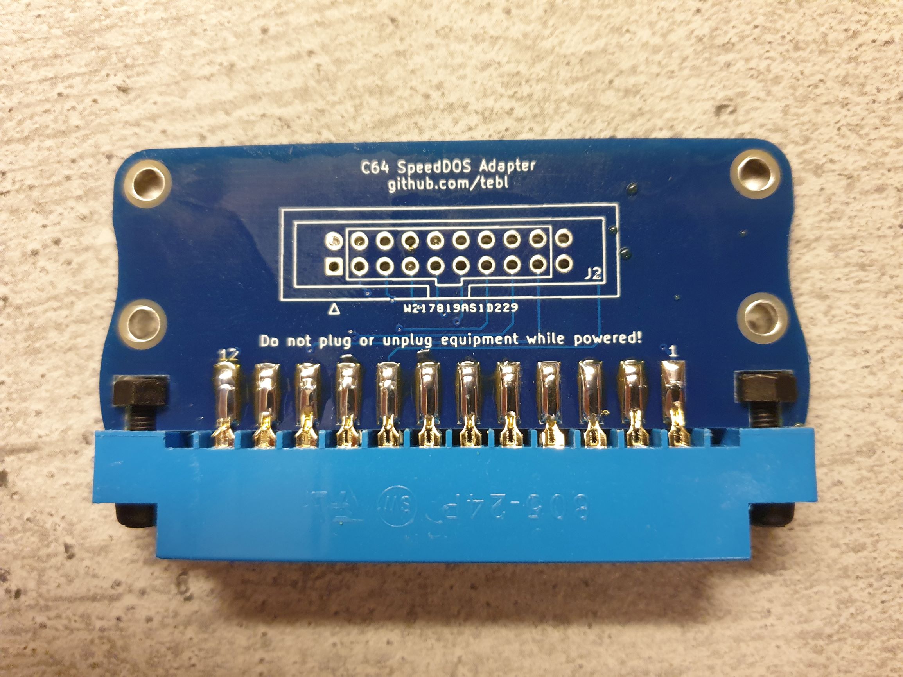
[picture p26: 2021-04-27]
gallery/build_speeddos_002.jpg

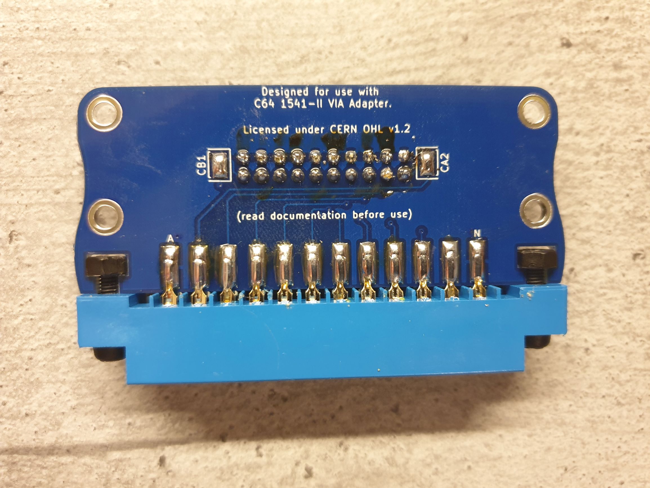
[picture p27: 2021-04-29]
gallery/build_speeddos_004.jpg

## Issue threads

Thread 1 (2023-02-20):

Not an Issue, just a big thank you, notes and an idea

venice1200, 2023-02-20:
Many Thanks for this project and your Adapter!
It's fun to get old hardware useful upgraded!

First, your XUM1541-II works great!

Second, I use your 1541-II ROM Adapter slightly modfied with my 1541-II to use CBM, JiffyDOS and S-JiffyDOS.
As S-JiffyDOS uses 32k the A14 Signal from the 6502 is needed at the ROM-IC.
To support this I added two more (bridged) connection points for the 6502-A14 Signal to the Rom-Switch at J1.
If you only use a S-JiffyDOS ROM you just bridge A14 to 6502-A14 with a jumper.
To get a bit space I changed R1 + R2 from THT to SMD.

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

Third, an Idea regarding your VIA Adapter.
If I am correct, the GND connection of PA0 (pin 2) of the 6522 must be cutted for parallel use if you use a 1541-II Floppy.
Why not adding an "virtual cut" to your adapter by removing the bridge between the two PA0 Pins (A1&U1)
or add an open solder bridge like you did for GND?

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

Many Thx again!

Closed 2023-10-13.

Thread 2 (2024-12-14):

Native USB-C support

mvbhz, 2024-12-14:
I bought the XUM1541-II. It looks the same as in the picture and has a USB-C socket. However, when I connect it to a computer or laptop with a USB-C > USB-C cable, the computer or laptop do not see the XUM1541-II. Only when I connect it with a USB-C > USB-A cable does it work. Is it possible to make native USB-C support in this device?

tebl, 2024-12-14:
I don't have a Pro Micro with USB-C, all of mine unfortunately have a Micro
USB interface. One thing to try though, try turning over the USB-C plug to
see if it works the other way - seen some strange USB-modules that had this
issue.

lør. 14. des. 2024 kl. 16:42 skrev mvbhz ***@***.***>:

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

SteveGuidi, 2024-12-15:
> I bought the XUM1541-II. It looks the same as in the picture and has a USB-C port. However, when I connect it to a computer or laptop with a USB-C > USB-C cable, the computer or laptop do not see the XUM1541-II. Only when I connect it with a USB-C > USB-A cable to a USB-A port on the computer does it work. Is it possible to make native USB-C support in this device?

This appears to be a limitation of many of the Pro-Micro boards:
https://www.reddit.com/r/arduino/comments/xbjhto/pro_micro_clone_usba_works_but_not_usbc/

mvbhz, 2024-12-15:
Reversing the USB-C plug did not help.

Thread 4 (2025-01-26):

Not detecting drive (Pi1541 or Real 1541), Reset command in CBMxfer does reset both types of drive

fistmaster2k4, 2025-01-26:
I ordered the PCB's from PCBWay and have built the device without any issue. The ProMicro firmware was installed using the avrdude method and windows drivers installed, again without issue.
The device shows in device manager as expected.
When sending cbmctrl detect I get nothing, no errors. The light on the Pro Micro flashes when the command is ran.
Using XBMxfer detect drive does nothing but make the light on the pro micro flash when the detect is ran, no drives are detected.

Hitting the reset drive button in XBMxfer does cause the pi1541 / 1541 reboot.

I've swapped the 7406 trying both a TI SN7406N and a LGS GD74LS06 both give same results.

I used both tebl's firmware xum1541-PROMICRO_7406-v08.hex and the firmware from the XUM floppy repository, both givng the same result.
I've checked and reflowed the board many times without any luck

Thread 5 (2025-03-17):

SpeedDos adapter STL or faceplate

PicoElements, 2025-03-17:
Hello, is there any STL enclosure for the SpeedDos Adapter or any faceplate to print?
it seems to be designed for one of them..
Thanks in advance,
Stefano

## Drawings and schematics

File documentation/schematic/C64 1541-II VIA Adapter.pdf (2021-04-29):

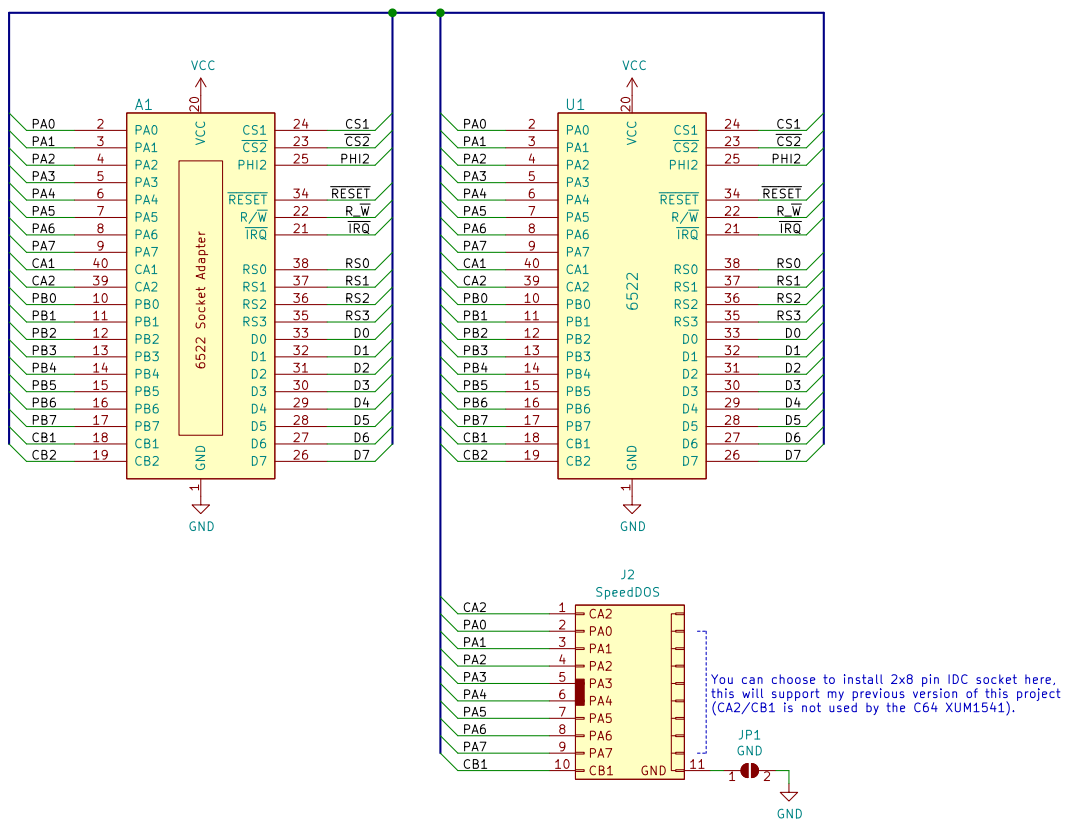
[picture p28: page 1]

this will support my previous version of this project
(CA2/CB1 is not used by the C64 XUM1541).
JP1 GND

File: C64 1541-II VIA Adapter.sch Sheet: /

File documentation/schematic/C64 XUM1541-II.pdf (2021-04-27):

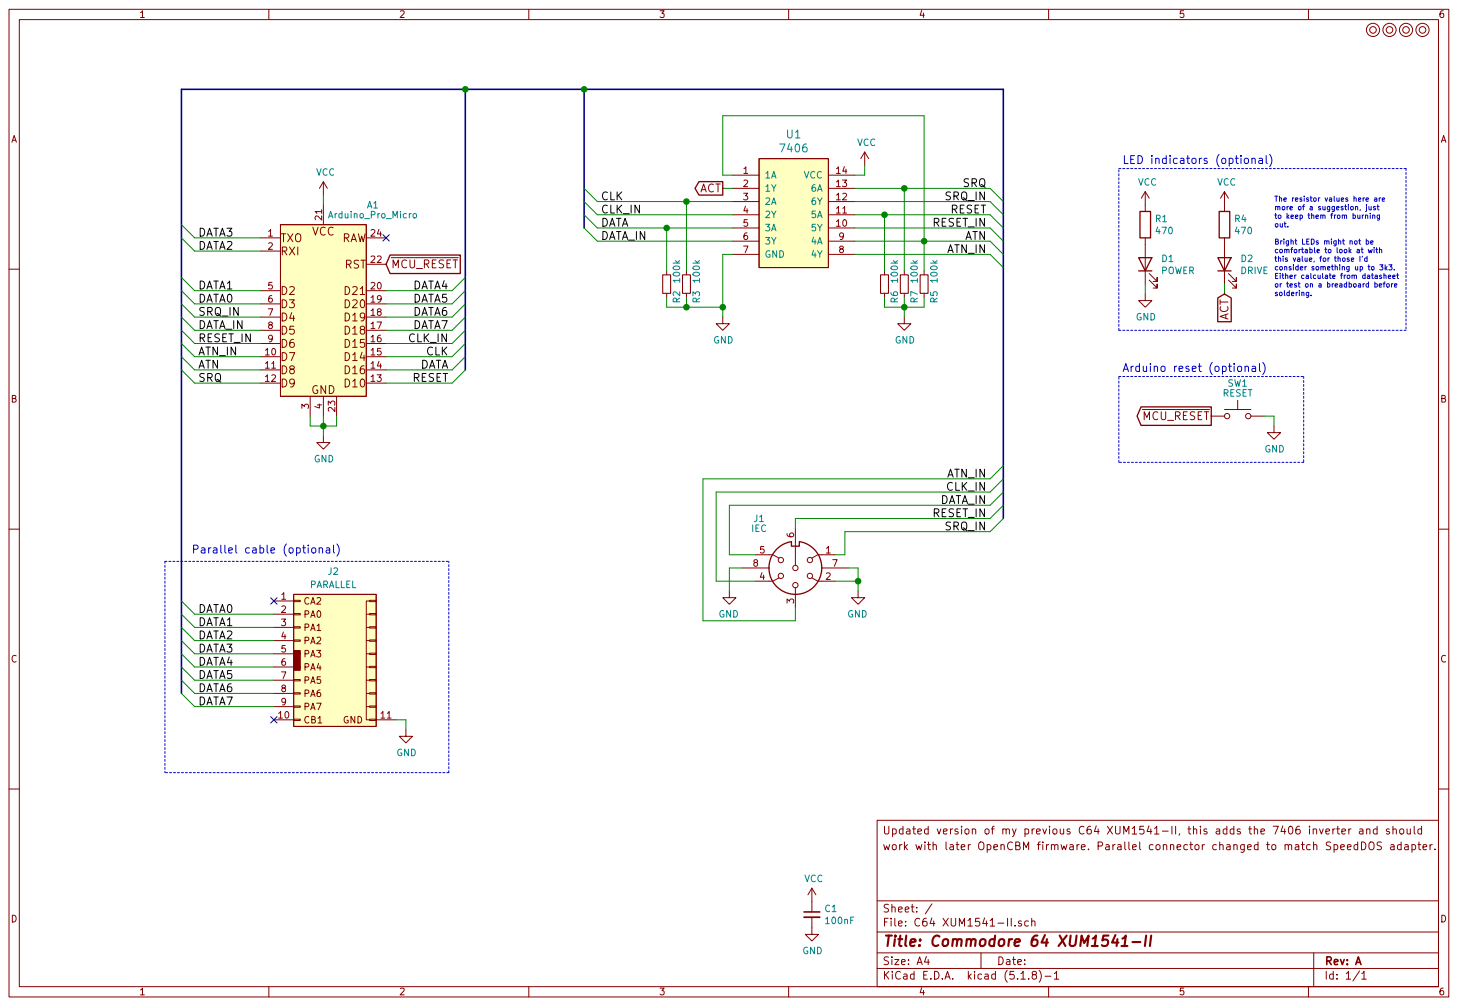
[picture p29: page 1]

VCC

The resistor values here are more of a suggestion, just

to keep them from burning
out. Bright LEDs might not be

ATN

comfortable to look at with
this value, for those I'd
consider something up to 3k3. Either calculate from datasheet or test on a breadboard before

soldering. Parallel cable (optional)

CLK_IN
DATA_IN
RESET_IN

Id: 1/1 Title: Commodore 64 XUM1541-II File: C64 XUM1541-II.sch Sheet: / work with later OpenCBM firmware. Parallel connector changed to match SpeedDOS adapter.

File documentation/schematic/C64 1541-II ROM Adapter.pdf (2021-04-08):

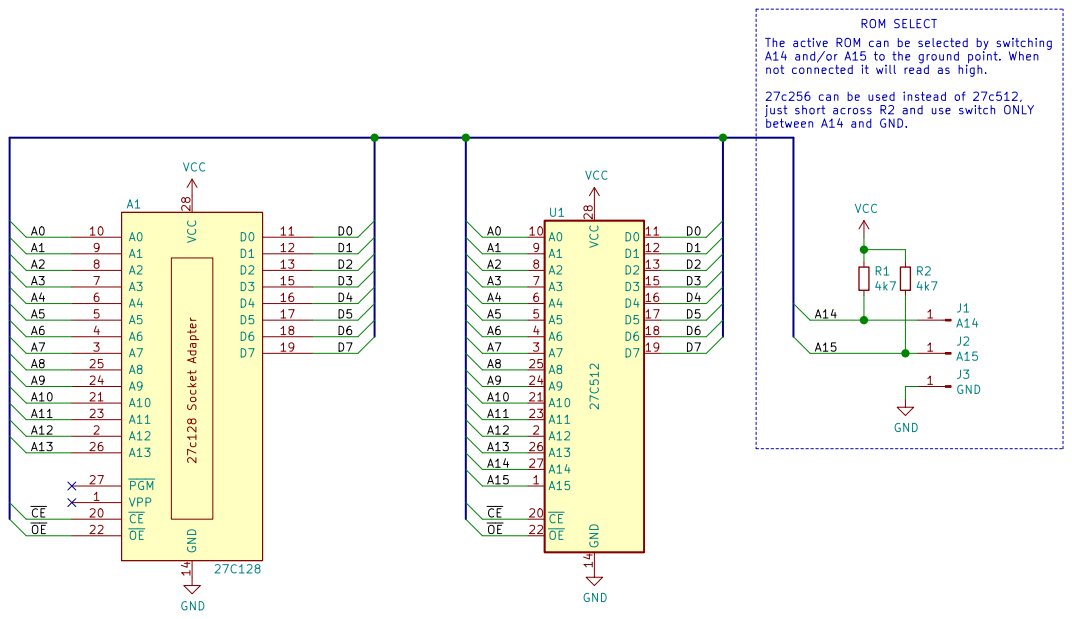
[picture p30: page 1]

The active ROM can be selected by switching
A14 and/or A15 to the ground point. When
not connected it will read as high. 27c256 can be used instead of 27c512,

just short across R2 and use switch ONLY
between A14 and GND.

File: C64 1541-II ROM Adapter.sch Sheet: / bending pins looks a bit too messy for my liking.

Id: 1/1 Title: C64 1541-II ROM Adapter

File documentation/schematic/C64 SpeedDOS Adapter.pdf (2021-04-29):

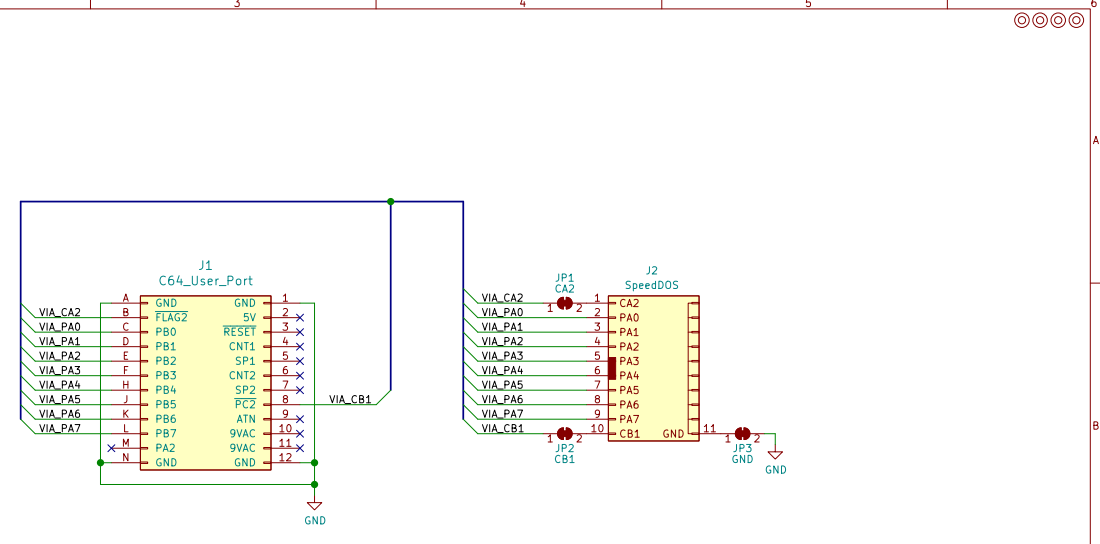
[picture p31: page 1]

File: C64 SpeedDOS Adapter.sch Sheet: / User Port adapter for using SpeedDOS.

Id: 1/1 Title: C64 SpeedDOS Adapter

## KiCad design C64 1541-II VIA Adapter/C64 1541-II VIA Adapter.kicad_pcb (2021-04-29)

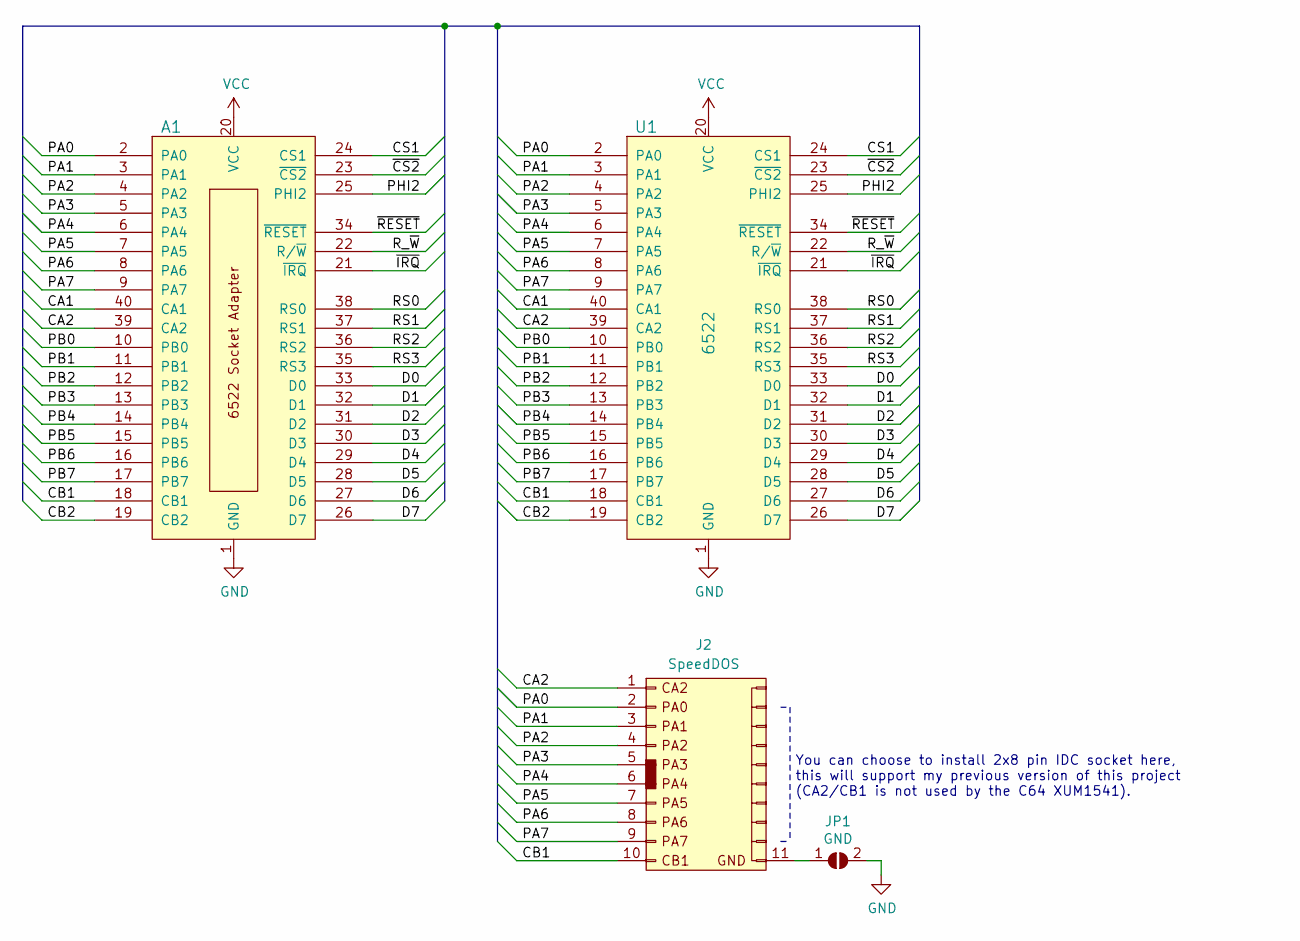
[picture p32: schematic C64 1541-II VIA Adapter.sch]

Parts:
A1: 6522_Adapter; DIP-40_W15.24mm_Socket
J2: SpeedDOS; SpeedDOS_IDC
JP1: GND; bridge_r
U1: 6522; DIP-40_W15.24mm_Socket

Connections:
/CA1: A1.40 (CA1), U1.40 (CA1)
/CA2: A1.39 (CA2), J2.1, U1.39 (CA2)
/CB1: A1.18 (CB1), J2.10, U1.18 (CB1)
/CB2: A1.19 (CB2), U1.19 (CB2)
/CS1: A1.24 (CS1), U1.24 (CS1)
/D0: A1.33 (D0), U1.33 (D0)
/D1: A1.32 (D1), U1.32 (D1)
/D2: A1.31 (D2), U1.31 (D2)
/D3: A1.30 (D3), U1.30 (D3)
/D4: A1.29 (D4), U1.29 (D4)
/D5: A1.28 (D5), U1.28 (D5)
/D6: A1.27 (D6), U1.27 (D6)
/D7: A1.26 (D7), U1.26 (D7)
/PA0: A1.2 (PA0), J2.2, U1.2 (PA0)
/PA1: A1.3 (PA1), J2.3, U1.3 (PA1)
/PA2: A1.4 (PA2), J2.4, U1.4 (PA2)
/PA3: A1.5 (PA3), J2.5, U1.5 (PA3)
/PA4: A1.6 (PA4), J2.6, U1.6 (PA4)
/PA5: A1.7 (PA5), J2.7 (Pin_5), U1.7 (PA5)
/PA6: A1.8 (PA6), J2.8, U1.8 (PA6)
/PA7: A1.9 (PA7), J2.9, U1.9 (PA7)
/PB0: A1.10 (PB0), U1.10 (PB0)
/PB1: A1.11 (PB1), U1.11 (PB1)
/PB2: A1.12 (PB2), U1.12 (PB2)
/PB3: A1.13 (PB3), U1.13 (PB3)
/PB4: A1.14 (PB4), U1.14 (PB4)
/PB5: A1.15 (PB5), U1.15 (PB5)
/PB6: A1.16 (PB6), U1.16 (PB6)
/PB7: A1.17 (PB7), U1.17 (PB7)
/PHI2: A1.25 (PHI2), U1.25 (PHI2)
/RS0: A1.38 (RS0), U1.38 (RS0)
/RS1: A1.37 (RS1), U1.37 (RS1)
/RS2: A1.36 (RS2), U1.36 (RS2)
/RS3: A1.35 (RS3), U1.35 (RS3)
/R_~W: A1.22 (R/~W), U1.22 (R/~W)
/~CS2: A1.23 (~CS2), U1.23 (~CS2)
/~IRQ: A1.21 (~IRQ), U1.21 (~IRQ)
/~RESET: A1.34 (~RESET), U1.34 (~RESET)
GND: A1.1 (GND), JP1.2 (B), U1.1 (GND)
unnamed: J2.11, JP1.1 (A)
VCC: A1.20 (VCC), U1.20 (VCC)

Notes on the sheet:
You can choose to install 2x8 pin IDC socket here, this will support my previous version of this project (CA2/CB1 is not used by the C64 XUM1541).

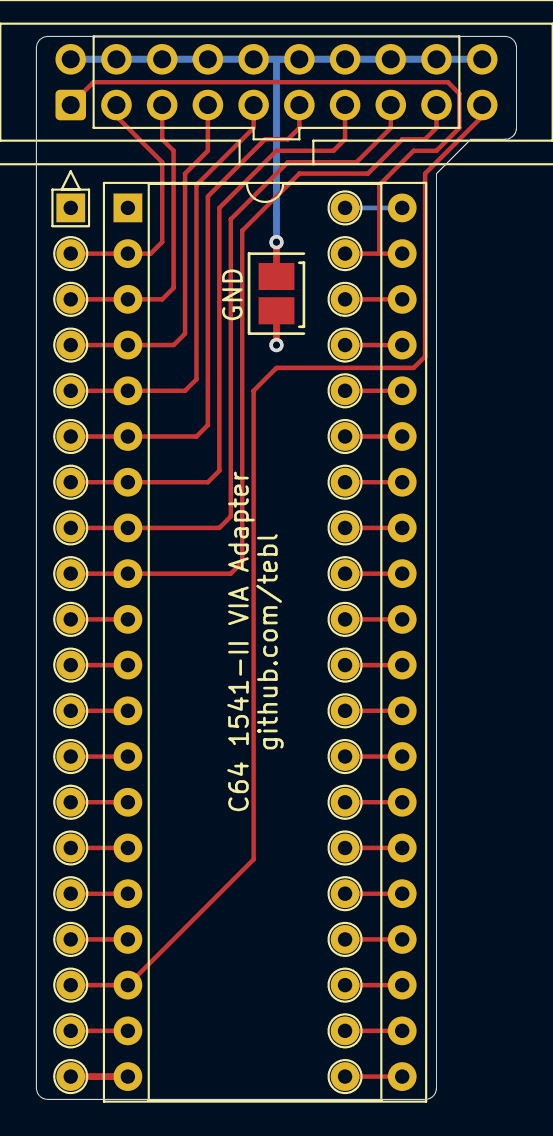
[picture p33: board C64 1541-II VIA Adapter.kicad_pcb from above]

Board: 2 copper layers, 26.7 x 59.1 mm, 4 parts (0 on the bottom side), 41 nets.

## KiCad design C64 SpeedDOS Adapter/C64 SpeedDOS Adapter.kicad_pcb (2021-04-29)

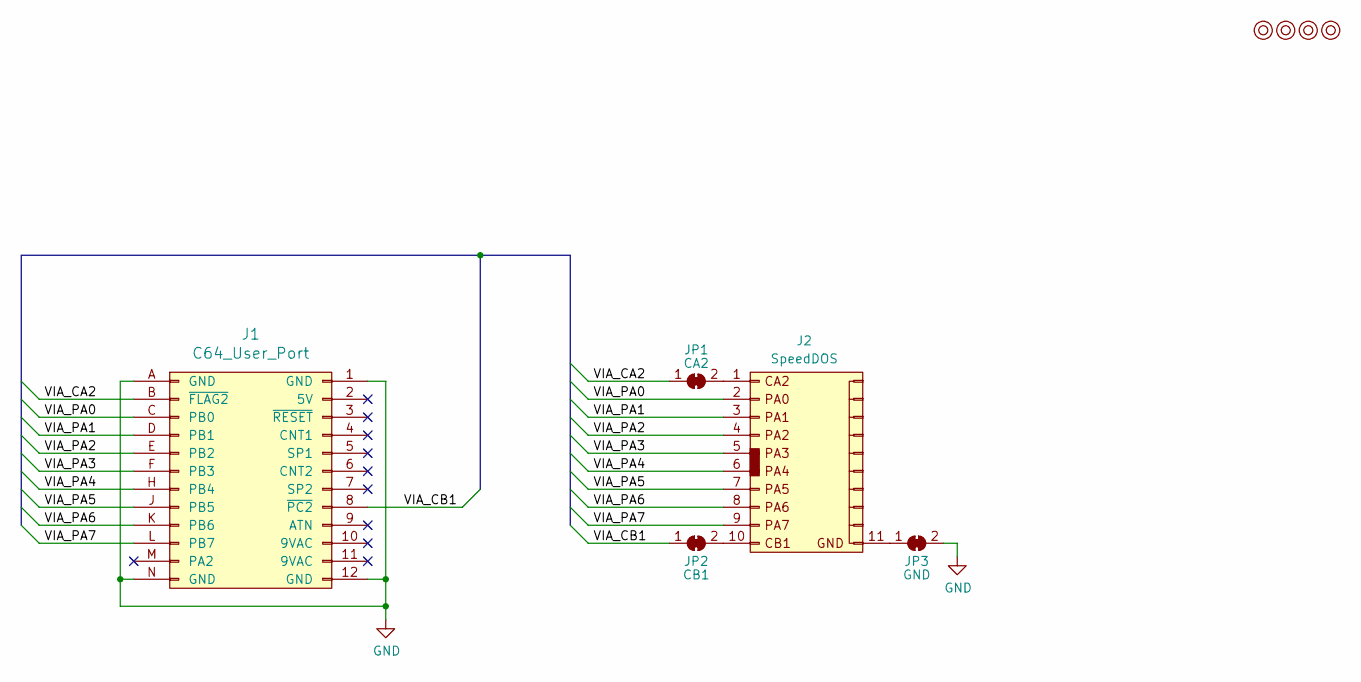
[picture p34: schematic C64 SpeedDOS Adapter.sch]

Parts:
J1: C64_User_Port; C64_User-Port
J2: SpeedDOS; SpeedDOS_IDC
JP1: CA2; bridge
JP2: CB1; bridge_r
JP3: GND; bridge
M1, M2, M3, M4: Mounting; M3_pin

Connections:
/VIA_CA2: J1.B (~FLAG2), JP1.1 (A)
/VIA_CB1: J1.8 (~PC2), JP2.1 (A)
/VIA_PA0: J1.C (PB0), J2.2
/VIA_PA1: J1.D (PB1), J2.3
/VIA_PA2: J1.E (PB2), J2.4
/VIA_PA3: J1.F (PB3), J2.5
/VIA_PA4: J1.H (PB4), J2.6
/VIA_PA5: J1.J (PB5), J2.7 (Pin_5)
/VIA_PA6: J1.K (PB6), J2.8
/VIA_PA7: J1.L (PB7), J2.9
GND: J1.1 (GND), J1.12 (GND), J1.A (GND), J1.N (GND), JP3.2 (B)
unnamed: J2.1, JP1.2 (B)
unnamed: J2.10, JP2.2 (B)
unnamed: J2.11, JP3.1 (A)

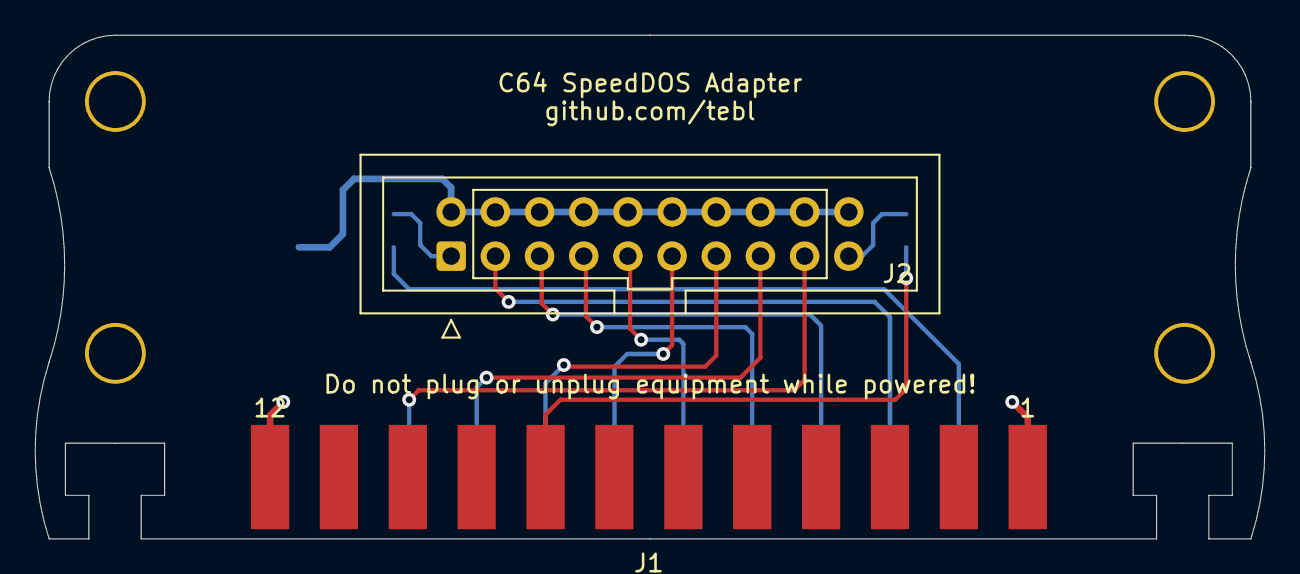
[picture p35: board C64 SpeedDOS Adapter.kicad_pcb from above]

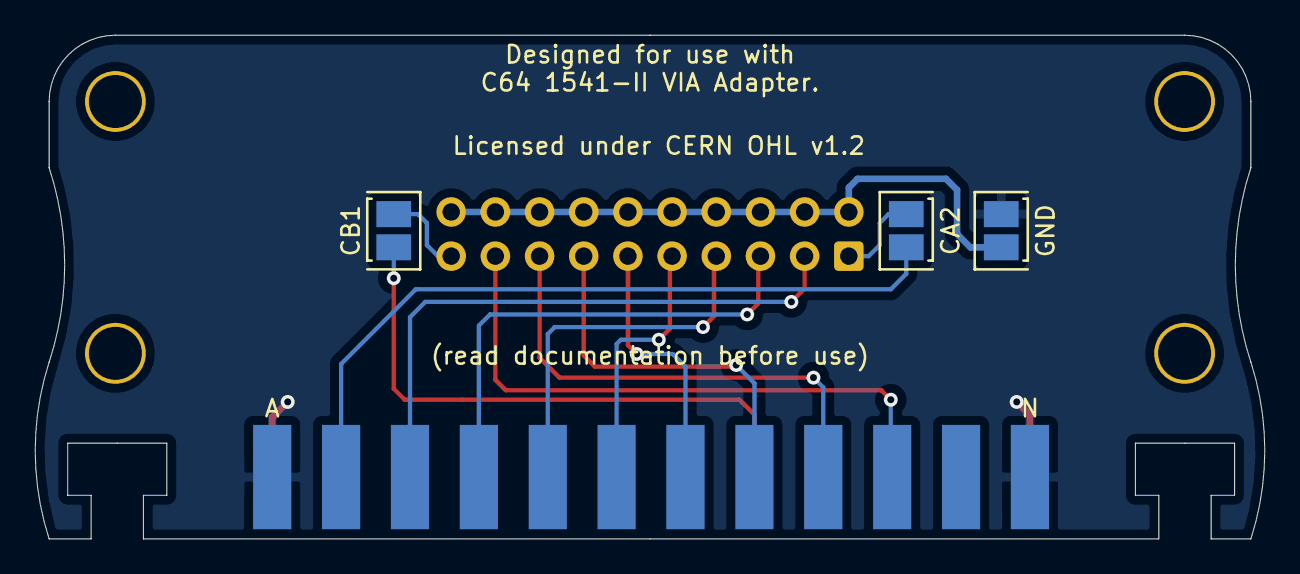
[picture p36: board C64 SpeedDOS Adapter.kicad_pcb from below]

Board: 2 copper layers, 70.7 x 29.0 mm, 9 parts (3 on the bottom side), 14 nets.

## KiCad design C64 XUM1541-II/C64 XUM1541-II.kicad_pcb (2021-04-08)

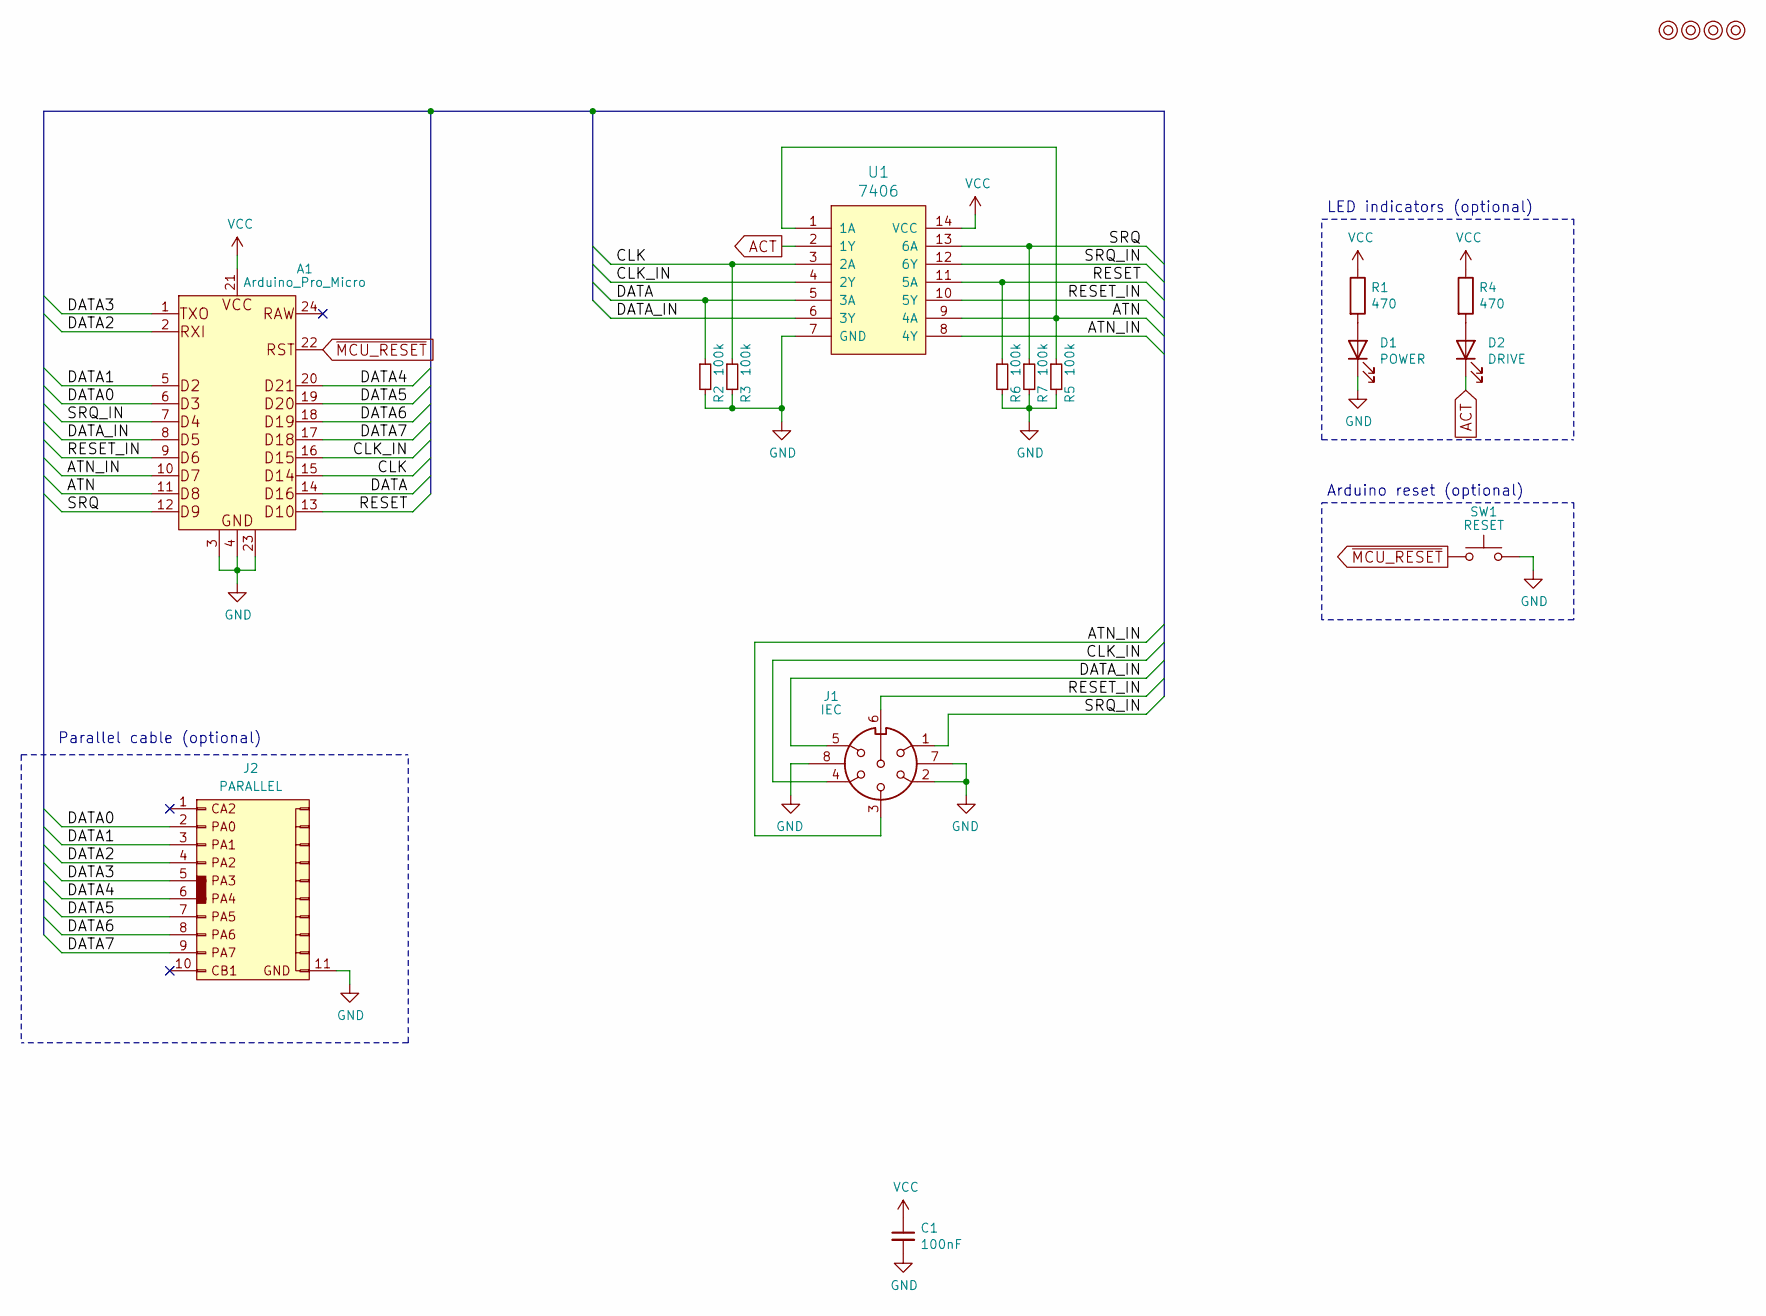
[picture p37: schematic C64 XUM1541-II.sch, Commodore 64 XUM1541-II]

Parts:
A1: Arduino_Pro_Micro
C1: 100nF; C_Disc_D4.7mm_W2.5mm_P5.00mm
D1: POWER; LED_D5.0mm
D2: DRIVE; LED_D5.0mm
J1: IEC; C64_IEC
J2: PARALLEL; SpeedDOS_IDC
M1, M2, M3, M4: Mounting; M3_pin
R1, R4: 470; R_Axial_DIN0207_L6.3mm_D2.5mm_P10.16mm_Horizontal
R2, R3, R5, R6, R7: 100k; R_Axial_DIN0207_L6.3mm_D2.5mm_P10.16mm_Horizontal
SW1: RESET; SW_PUSH_6mm
U1: 7406; DIP-14_W7.62mm_Socket_LongPads

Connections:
/ATN: A1.11 (D8), R5.1, U1.1 (1A), U1.9 (4A)
/ATN_IN: A1.10 (D7), J1.3, U1.8 (4Y)
/CLK: A1.15 (D14), R3.1, U1.3 (2A)
/CLK_IN: A1.16 (D15), J1.4, U1.4 (2Y)
/DATA: A1.14 (D16), R2.1, U1.5 (3A)
/DATA0: A1.6 (D3), J2.2
/DATA1: A1.5 (D2), J2.3
/DATA2: A1.2 (RXI), J2.4
/DATA3: A1.1 (TXO), J2.5
/DATA4: A1.20 (D21), J2.6
/DATA5: A1.19 (D20), J2.7 (Pin_5)
/DATA6: A1.18 (D19), J2.8
/DATA7: A1.17 (D18), J2.9
/DATA_IN: A1.8 (D5), J1.5, U1.6 (3Y)
/RESET: A1.13 (D10), R6.1, U1.11 (5A)
/RESET_IN: A1.9 (D6), J1.6, U1.10 (5Y)
/SRQ: A1.12 (D9), R7.1, U1.13 (6A)
/SRQ_IN: A1.7 (D4), J1.1, U1.12 (6Y)
ACT: D2.1 (K), U1.2 (1Y)
GND: A1.3 (GND), A1.4 (GND), A1.23 (GND), C1.2, D1.1 (K), J1.2, J1.7, J1.8, J2.11, R2.2, R3.2, R5.2, R6.2, R7.2, SW1.2, U1.7 (GND)
unnamed: D1.2 (A), R1.2
unnamed: D2.2 (A), R4.2
VCC: A1.21 (VCC), C1.1, R1.1, R4.1, U1.14 (VCC)
~MCU_RESET: A1.22 (RST), SW1.1

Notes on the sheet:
LED indicators (optional)
Parallel cable (optional)
Arduino reset (optional)

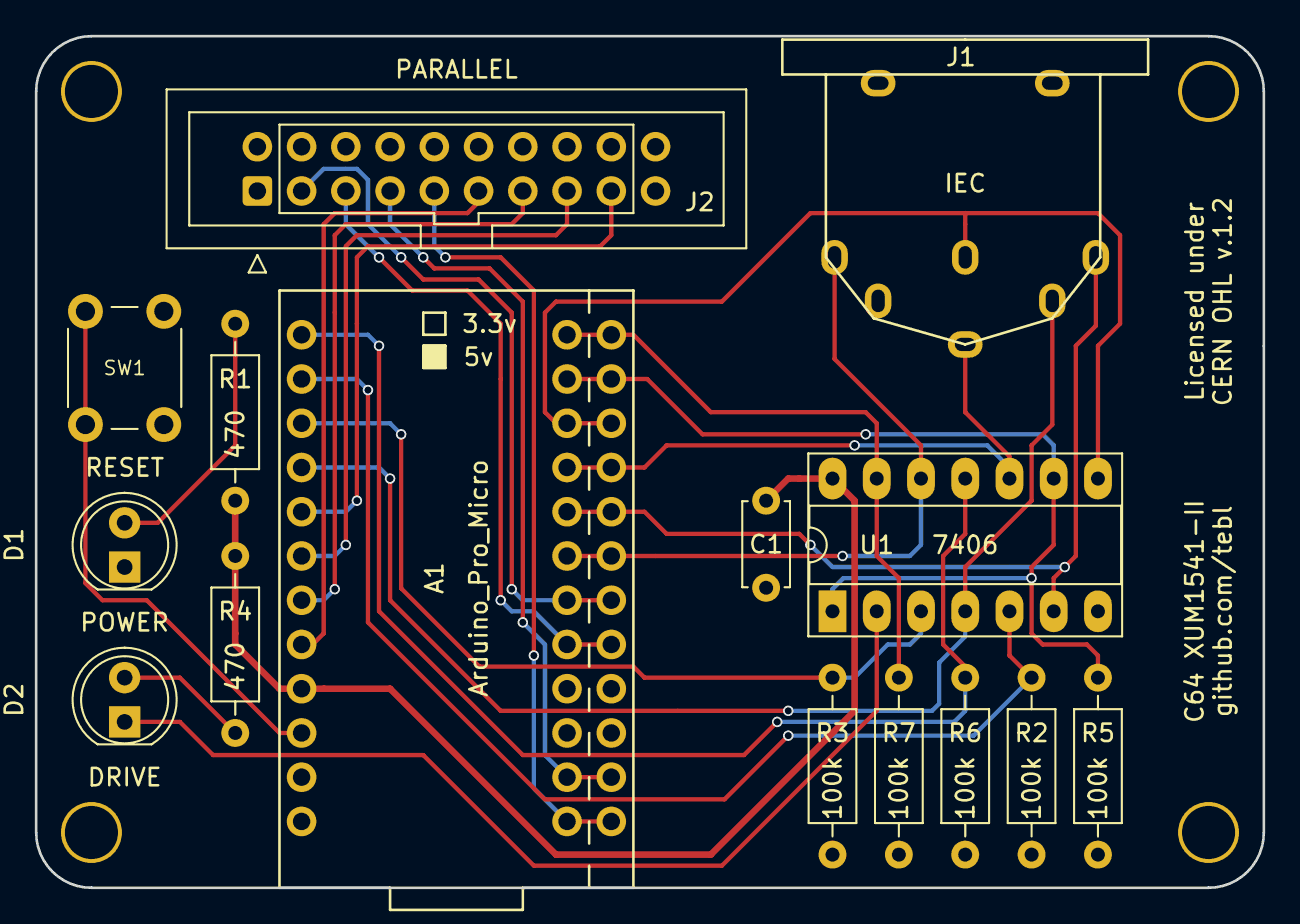
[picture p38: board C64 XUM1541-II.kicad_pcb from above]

Board: 2 copper layers, 70.5 x 48.9 mm, 19 parts (0 on the bottom side), 24 nets.

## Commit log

2021-03-09 Updated schematic to add 7406
2021-03-09 First VIA adapter sketch
    [C64 1541-II VIA Adapter.kicad_pcb, C64 1541-II VIA Adapter.sch, C64 XUM1541-II.kicad_pcb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]
2021-03-10 User port adapter added
    [C64 1541-II VIA Adapter.kicad_pcb, C64 1541-II VIA Adapter.sch, C64 SpeedDOS Adapter.kicad_pcb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]
2021-03-10 First new layout draft
    [C64 XUM1541-II.kicad_pcb, C64 XUM1541-II.sch]
2021-03-10 Silkscreen tweaks and gerber exports
    [C64 1541-II VIA Adapter-B_Cu.gbl, C64 1541-II VIA Adapter-B_Mask.gbs, C64 1541-II VIA Adapter-B_Paste.gbp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]
2021-03-18 ACTIVITY is now DRIVE LED
    [C64 XUM1541-II.kicad_pcb, C64 XUM1541-II.sch]
2021-03-19 Updated silkscreen
    [C64 XUM1541-II-B_Cu.gbl, C64 XUM1541-II-B_Mask.gbs, C64 XUM1541-II-B_Paste.gbp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]
2021-03-20 Increase space for M3 nut
    [C64 SpeedDOS Adapter.kicad_pcb, C64 XUM1541-II.sch]
2021-04-07 Moved connector to clear stepper motor
    [C64 1541-II VIA Adapter-B_Cu.gbl, C64 1541-II VIA Adapter-B_Mask.gbs, C64 1541-II VIA Adapter-B_Paste.gbp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]
2021-04-07 Rotated parallel connector
    [C64 XUM1541-II-B_Cu.gbl, C64 XUM1541-II-B_Mask.gbs, C64 XUM1541-II-B_Paste.gbp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]
2021-04-08 Updated gerber files and small tweaks
    [C64 1541-II ROM Adapter-B_Cu.gbl, C64 1541-II ROM Adapter-B_Mask.gbs, C64 1541-II ROM Adapter-B_Paste.gbp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]
2021-04-08 Added schematic
2021-04-08 Shorten ROM board a little bit
    [C64 1541-II ROM Adapter-B_Cu.gbl, C64 1541-II ROM Adapter-B_Mask.gbs, C64 1541-II ROM Adapter-B_Paste.gbp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]
2021-04-08 Schematic notes added
    [C64 XUM1541-II.sch]
2021-04-09 Added note about device
2021-04-27 Resistor note
    [C64 XUM1541-II.sch]
2021-04-29 Added GND jumper to adapter
    [C64 SpeedDOS Adapter-B_Cu.gbl, C64 SpeedDOS Adapter-B_Mask.gbs, C64 SpeedDOS Adapter-B_Paste.gbp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]
2021-04-29 Link remaining pins
    [C64 1541-II VIA Adapter-B_Cu.gbl, C64 1541-II VIA Adapter-B_Mask.gbs, C64 1541-II VIA Adapter-B_Paste.gbp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]
2021-04-29 Added GND jumper
    [C64 1541-II VIA Adapter-B_Cu.gbl, C64 1541-II VIA Adapter-B_Mask.gbs, C64 1541-II VIA Adapter-B_Paste.gbp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]
2021-04-29 Gerber export
    [C64 1541-II VIA Adapter-B_Cu.gbl, C64 1541-II VIA Adapter-B_Mask.gbs, C64 1541-II VIA Adapter-B_Paste.gbp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]
2021-05-07 Arduino boards
2021-05-19 Added faceplate
    [C64 XUM1541-II FA1-B_Cu.gbl, C64 XUM1541-II FA1-B_Mask.gbs, C64 XUM1541-II FA1-B_Paste.gbp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]
2022-01-25 Alternative faceplate
    [C64 XUM1541-II FA2-B_Cu.gbl, C64 XUM1541-II FA2-B_Mask.gbs, C64 XUM1541-II FA2-B_Paste.gbp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]

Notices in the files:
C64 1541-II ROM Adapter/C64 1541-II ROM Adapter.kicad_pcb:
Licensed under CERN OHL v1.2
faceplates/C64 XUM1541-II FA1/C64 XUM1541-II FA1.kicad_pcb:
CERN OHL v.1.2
